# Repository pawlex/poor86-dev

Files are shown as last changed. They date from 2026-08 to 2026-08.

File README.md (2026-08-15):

# Poor86

A 386/486-class PC motherboard, in mini-ITX, built around a real x86 CPU
and an FPGA chipset — with every part of the machine that nobody loves
replaced by something modern.

It boots DOS. It has no hard disk, no battery, no legacy expansion
slots, no drive bays, and no shelf of discs. It fits in a case you can live with.

Decisions here are made on latency and phase coupling rather than raw
bandwidth: at 33 MHz with a four-word burst window, bandwidth is rarely
what binds. Slack is left in deliberately — spare capacity is usually
where the next idea lands.

Constraints are stated before solutions, and the reasoning behind each
decision is written down, wrong turns included. Source records what was
built; only a decision record explains why. That record is where the
project actually lives, and it is what would let someone else continue
the work rather than restart it.

---

## Why

### Love of the game

The interesting engineering is still here. A 486 local bus with burst
transfers, write-back cache control and coherency is a genuinely hard
problem, and building a chipset front end for it in programmable logic
is the kind of work that is worth doing for its own sake. The memory
subsystem and the bus interface caching are the heart of this project —
and they are deliberately scheduled **last**, because starting with the
best part is how the other ninety percent never gets finished.

### Giving back

The retro community has already solved most of the practical problems of
keeping these machines alive — floppy emulators, IDE replacements,
sound cards on modern microcontrollers, video scalers, USB adapters.
They exist as separate projects, separate purchases and separate wiring.

This assembles them into one board, and gives the work back: open
hardware, open RTL, and an entirely open toolchain (yosys, nextpnr,
Verilator — no vendor tools anywhere in the flow). Fixes found in
upstream projects go back upstream.

### The effort is already worth it, finished or not

This sat as an idea for years. Not for lack of interest — for lack of
time against its scope. It spans PCB design, an FPGA chipset, period bus
protocols, firmware, x86 emulation and controller software, and each of
those is somebody's full-time specialism. Any one of them is a weekend.
All of them together is a wall.

These sub-projects had been put off for years because they are hard —
but they are hard in a specific way that is worth naming, because it
changes what to do about them. **Most of them are wide, not deep.**

A deep problem needs insight you do not yet have. A wide one needs you
to be fluent in a domain you are not fluent in: the SeaBIOS source tree,
a Cirrus register map, an ECP5 memory primitive, the ATAPI packet
interface. Every step is tractable; the cost is the ramp-up, and it
resets every time you put the project down. That is precisely why wide
problems stall on evenings and weekends — the evening goes on reloading
context and never reaches the work.

Very little of the progress here came from cleverness. A months-old
question about the bus was answered by running one existing emulator
configuration. The peripheral models turned out to already exist in a
fork of the project. The video BIOS itself specified what the hardware
must implement, once somebody read it. None of that was hard. It was
*unread*.

Which leaves the genuinely deep part — the memory subsystem and the bus
interface caching — as the smallest fraction of the work, and the part
the author is actually equipped for. The wall was never the interesting
problem. It was the dozen uninteresting ones standing in front of it.

Working with an AI assistant (Claude) is what got past them. **And the
point worth making plainly is this: even if the board is never finished,
the effort has not been wasted.** Real problems have been solved, and they
stand on their own:

- **A working co-simulation harness.** An x86 interpreter running
  natively drives real RTL through a Wishbone bus-functional model, so
  chipset logic can be developed and regression-tested without a CPU in
  the simulation. It is reusable well beyond this project.
- **SeaBIOS completes POST against it**, on a non-PCI ISA machine with a
  deliberately minimal device set — a reproducible configuration, not a
  one-off.
- **A real bug found upstream**, in the tiny386 interpreter: its
  instruction-fetch cache retained a physical address for MMIO pages,
  reading out of bounds. Fixed, documented, and a candidate to send
  back.
- **A bounded specification for Cirrus-compatible video**, derived by
  reading what the video BIOS actually touches rather than guessing —
  including the finding that the blitter is not required at all.
- **Measured budgets rather than assumed ones** — bitstream size, block
  RAM limits, LUT and timing figures across candidate cores.

The larger shift is harder to point at but matters more. **A great deal
of this design has moved from "it could be done, with caveats" into an
active plan** — decisions made, alternatives eliminated for stated
reasons, and the reasoning written down where it can be checked. The
caveats that remain are now specific and small enough to attack.

Every decision here is the author's. The assistance is in reach and
throughput, and in not losing the reasoning between sessions — which,
for a project this wide worked on in evenings, turns out to be the
binding constraint.

**So this is also a case study**, kept in the open so it can be judged
rather than claimed. What has characterised it: check for the existing
thing before building a new one; measure instead of arguing; and keep
the corrections on the record — several conclusions in
[docs/PLAN_OF_RECORD.md](docs/PLAN_OF_RECORD.md) reversed once evidence arrived,
and the superseded reasoning still sits beside what replaced it.

There is a lot of noise about what this technology is for. This is one
answer: **real engineering problems, not cat videos.**

### Not just nostalgia

Nostalgia would mean reproducing a 1993 machine faithfully, defects
included, and accepting that it is expensive, fragile and annoying to
own. That is a museum piece.

The aim is different: **the era should be accessible to people who were
priced out of it, and pleasant enough to actually use.** Period hardware
has become scarce and costly; a working machine is now several hundred
pounds of separate purchases plus ongoing maintenance. This should cost
a fraction of that and ask nothing of its owner beyond plugging it in.

That said — the specific machines are not arbitrary. **A 386SX was the
author's first computer, and a 486SLC2 the first upgrade, paid for with
paper-round money.** Those configurations are a requirement, not a
technical trade-off. Everything modern in this design exists so that
*those* machines can be delivered without the burden that otherwise
makes them unusable.

---

## The organising principle

> **Authenticity is required at the guest-visible register interface.
> Everything behind it should be modern.**

A real x86 is soldered to this board. It, and the DOS software above it,
can only see registers and bus cycles — so that is the only place
period-correctness buys anything. Behind that boundary, reproducing 1993
is cost without benefit, and frequently worse: analogue output stages,
battery-backed NVRAM and spinning media are things to be rid of, not
honoured.

| | authentic front end | modern back end |
|---|---|---|
| storage | IDE / ATAPI registers | controller-served images |
| network | NE2000 registers | WiFi |
| keyboard, mouse | 8042 and PS/2 | USB HID |
| video | Cirrus-compatible registers | HDMI, or real CL-GD5428 for a CRT |
| RTC and CMOS | 128 legacy registers | NTP, no battery |
| sound | SB16 / AdLib registers | software synthesis, modern DAC |

Two corollaries that have saved a great deal of work:

- **Do not own what you can inherit.** SeaBIOS and SeaVGABIOS already
  support this machine. Shape the hardware so their existing code paths
  apply, rather than writing or patching firmware.
- **Do not reinvent what already exists.** Check first. Most of what
  this project needs has been found rather than written.

---

## Goals

- **Boots DOS**, on real x86 silicon, out of the box, with nothing
  attached.
- **mini-ITX (170 x 170 mm)**, in a case that can live on a desk.
- **Low bill of materials.** Every function moved into the FPGA or the
  board controller is a part that does not have to be bought, fitted or
  sourced.
- **Open end to end** — hardware, RTL, and toolchain.
- **No maintenance burden.** No battery to replace, no drive to fail, no
  media to store.
- **Usable by someone who is not the author**, which is a higher bar
  than working.

### Non-goals

- Museum-grade period accuracy behind the register interface.
- **Legacy expansion slots.** They do not fit the form factor, and
  building around scarce period cards is a dead end. Specific legacy
  silicon is supported directly, on a mezzanine; new work arrives on a
  modern header.
- Windows. DOS is the target; anything further is a bonus.
- Being the fastest anything. A period machine that works beats a fast
  one that does not exist.

---

## What is on the board

- **A soldered x86.** A 386/486 SL/SLC-class part, or an **Am5x86-133**
  — abundant as NOS, 486DX4-class, and the part that makes the machine
  more than a curiosity. **3.3 V is a requirement**, because it lets the
  entire CPU bus connect to the FPGA without level shifters — plausibly
  the largest single saving in the design.
- **An ECP5 FPGA** carrying the chipset and the peripherals, so a
  discrete 8259, 8254, 8042 and NE2000 are LUTs rather than packages.
- **An ESP32** as board controller: NTP for the clock, WiFi for the
  network, and the back end for storage.
- **A RISC-V soft core** inside the FPGA, which serves fallback
  configuration when the controller is unavailable, and which can run an
  x86 interpreter so that a board works with no period CPU fitted at all.
- **Video**, either from the FPGA over HDMI, or a real **CL-GD5428** on
  the local bus for driving a CRT.

General placement of the Poor86 board

*General placement only — orientation is not fixed. What is fixed is
which block connects to which FPGA edge, because that is derivable from
the datasheets now rather than discovered during layout. Pin counts are
counted from `Data/pinmap_*.csv`, not estimated. See
[PLACEMENT.md](docs/PLACEMENT.md).*

---

## Sub-projects

| repo | what it is | why it exists |
|---|---|---|
| [vexrv-cpu-oss](https://github.com/pawlex/vexrv-cpu-oss) | the RISC-V soft core, the x86 interpreter payload, and the Verilator co-simulation | the chipset is developed and debugged against it, so most of the machine can be made to work before a board exists |
| [ao486-cpu-oss](https://github.com/pawlex/ao486-cpu-oss) | the ao486 486-class x86 soft core packaged for the open toolchain — Verilator regression suite, plus synthesis and place-and-route with no vendor tools. Places and routes on an ECP5-85F at 32.87 MHz | **so the machine outlives the supply of period CPUs.** NOS Am5x86 is finite and not being made again; when it runs out, the board has to remain buildable, and a 486-class core inside the FPGA is how |
| [tiny386](https://github.com/pawlex/tiny386) | fork of the x86 interpreter, ported to bare-metal RV32 | gives the soft core an x86 to run, so a board with no period CPU fitted at all still boots |
| [ecp5-oss-skeleton](https://github.com/pawlex/ecp5-oss-skeleton) | ECP5 project template and the block-RAM findings behind it | keeps the entire flow on open tooling, with no vendor toolchain anywhere in it |

Firmware comes from [SeaBIOS](https://www.seabios.org/) and SeaVGABIOS,
unmodified where possible.

---

## Status

Early. The schematics and library work are in `PCB/`; reference material
is in `Data/`.

On the simulation side, SeaBIOS already completes POST against the
chipset model in Verilator, with real RTL in the transaction path.

**The memory subsystem and the bus interface caching are deliberately
unspecified.** They are the most interesting part of the work and they
are being left until the rest is done.

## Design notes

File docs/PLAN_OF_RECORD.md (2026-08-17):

# Plan of record

The architecture record for Poor86: what is decided, what is open, and
**why** — including the reasoning that was wrong on the way, because a
decision without its rejected alternatives tends to get re-litigated.

Motivation, goals and the organising principle are in
[../README.md](../README.md). This file is the detail beneath them.

Two conventions carried throughout:

- **If a decision would assume a particular memory-subsystem design, it
  is flagged rather than assumed.** The memory subsystem is being
  specified last, deliberately.
- **Corrections stay on the record.** Several conclusions here reversed
  once evidence arrived; the superseded reasoning is kept beside what
  replaced it.

Implementation and the simulation environment live in
[vexrv-cpu-oss](https://github.com/pawlex/vexrv-cpu-oss).

## Status: nothing here is built, and almost nothing is chosen

**Read this first.** *Plan of record* is meant literally: this is the
currently-agreed plan, and it is expected to change. It is not a
specification and it is not a commitment.

No hardware exists. Nothing is committed to, nothing is irreversible,
and several conclusions in this document reversed within the
conversation that produced them. What exists is a co-simulation, some
measurements, and a set of things that have been **ruled out**.

That is not a weak position. **Ruling something out is forward
progress, and the more durable kind** — an elimination backed by a
reason survives new information, where a selection made early usually
does not. "PCI is out, because the bus is 16-bit and SeaBIOS supports
non-PCI as a first-class configuration" stays true regardless of what
comes next. "We will use serial PSRAM" would not.

So the headings are labelled by what they actually are:

| label | meaning |
|---|---|
| **Requirement** | given as a constraint, not derived here. Not up for re-derivation. |
| **Eliminated** | ruled out, with a reason intended to outlive the moment |
| **Direction** | the current preference and its reasoning. **Not settled.** |
| **Design goal** | a property the machine should have |
| **OPEN** | actively unresolved, and blocking something |

A record is allowed to hold two positions in tension; a specification is
not. **This is a record.** Where two sections disagree — and some do,
marked *Contested* — that is the document working correctly, not a
defect to be tidied away.

## Requirement: one soldered CPU, SX-class bus, 3.3 V

**There is no socket.** All parts are soldered down, and there is exactly
one CPU — a **386/486 SL/SLC-class part in PGA100, 3.3 V VCC**.

That resolves what looked like the hard decision. The cost weighted
heaviest — two bus front ends for a dual-socket board — **does not
exist**. There is one bus, one front end, one set of validation.

### What follows

```
  one SX-class CPU  ->  16-bit data, 24-bit address
                    ->  no PCI (32-bit, anachronistic)
                    ->  no VL-Bus slot; local-bus video still fine
                    ->  ISA-class programming model
                    ->  16 MiB guest RAM ceiling
```

The ceiling is now a property of the machine rather than of which part
someone fitted, which is simpler to design and document against.

### 3.3 V is the important part

**A 3.3 V CPU interfaces directly to the ECP5.** The FPGA's I/O banks
drive and receive LVCMOS33, so the entire CPU bus — every address, data
and control line — connects without level shifters.

At 5 V this would need translation on dozens of signals: parts, board
area, propagation delay on the timing-critical path, and a failure mode
on every one of them. Requiring 3.3 V removes all of it. This is
plausibly the single largest BOM and area saving in the design, and it
is consistent with the mini-ITX and cost goals.

### Why SL/SLC is a good fit beyond the voltage

The SLC-class parts pair a **386SX-style bus with the 486 instruction
set** and a small on-chip cache. So the chipset sees the simpler 16/24
bus while the software sees a 486 — better compatibility for the same
front-end effort. They are also low power, need no heatsink, and come in
a package that suits mini-ITX far better than a 486 PGA with a cooler
on top.

### The 486 part: Am5x86-133

For the record, the 486-class option is an **Am5x86 at 133 MHz**,
abundantly available as NOS — which answers the sourcing concern raised
against period parts elsewhere. It is 486DX4-class with a 16 KiB
write-back L1, and **3.3 V**, so the no-level-shifter property above
holds for it as well.

**Its bus is 33 MHz, not 133.** The 133 is a 4x internal multiplier. The
FPGA chipset only ever has to meet the 33 MHz bus, and against the Fmax
figures already measured on this device — VexRiscv variants at 99-108
MHz, ao486 at 32.87 MHz out-of-context — that is roughly 3x headroom on
the front end. It stays comfortable as the device fills.

### ...and it brings the hardest chipset problem

The Am5x86 is the fast part *and* the difficult one. Its bus is **32-bit,
bursting, pipelined, with cache control** — and with a **write-back L1**,
which is the part that hurts.

What the chipset has to deal with that an SX-class bus does not:

| signal / behaviour | why it is work |
|---|---|
| `BRDY#` / `BLAST#` bursts | 4-transfer cache line fills, not single cycles |
| `KEN#` | the chipset decides, per cycle, what is cacheable |
| `FLUSH#` | forced write-back and invalidate |
| `AHOLD` / `EADS#` / `INV` | snooping — an external address driven *into* the CPU |
| write-back L1 | **the CPU can hold dirty lines the chipset does not have** |

That last row is the real problem, and it is a *coherency* problem rather
than a timing one. Anything else writing guest memory — the ESP32
serving storage, the soft core, any DMA-equivalent — can be writing
underneath a dirty line the CPU has not flushed.

Three ways out, in increasing order of cost:

**A.** **Never assert `KEN#`.** External memory is uncacheable, the L1 is
   effectively disabled, coherency evaporates. Simplest possible chipset
   — and throws away most of what the 133 MHz part was bought for.
**B.** **Cacheable but no burst.** Assert `KEN#`, answer each of the four
   transfers with a normal ready rather than `BRDY#`. Line fills cost 4
   cycles instead of a burst, but the cache works. Still needs a
   coherency answer.

**C.** **Selective cacheability plus snooping.** `KEN#` asserted only for
   regions no other agent writes, snooping via `AHOLD`/`EADS#` for the
   rest. Fastest and hardest. A behavioural sketch of this one exists —
   see [BIU_MEMSS.md](BIU_MEMSS.md), **Concept C** — which is an
   exploration, not a proposal.

Note (A) and (B) make the *coherency* question mostly disappear, which is
worth weighing: the difficulty is not evenly distributed across the
options.

**Deliberately deferred.** Burst and caching support are not on the
critical path to a first board. The soft core makes the hardware useful
without them, so this is scheduled after production rather than before
it — and it is another reason the memory subsystem stays open, since the
cacheability and coherency policy is downstream of what sits behind the
BIU.

- [ ] **Masked writes, or full cache-line writes with read-fill?**
      Does the memory controller honour byte enables via `DQM`, or does it
      only ever write whole lines — turning any partial write into a
      **read-modify-write**?

      **The cost of getting it wrong is latency, on the path the whole
      design is organised around.** An RMW pays a full read before the
      write: `tRCD` + `CL` ≈ 60 ns at 66 MHz, against a 30 ns CPU cycle.
      **`DQM` masking costs nothing** — the two pins are already in the
      budget and SDRAM supports it natively.

      **The 32→16 split maps byte enables cleanly.** A 32-bit CPU write is
      two 16-bit SDRAM cycles, so `BE0`/`BE1` become the first cycle's
      `DQM[1:0]` and `BE2`/`BE3` the second. No encoding problem.

      **But it is coupled to the cache policy below, and may be moot.**
      With **write-back plus write-allocate**, partial writes land in the
      cache and lines are written back whole — `DQM` is then barely
      exercised. With **write-through, no-allocate, or any uncached
      region**, partial writes reach memory directly and masking becomes
      essential. **Decide the cache policy first; this follows from it.**

      **The video path does not share the question.** QSPI PSRAM is
      byte-addressable — a write command carries a byte address — so the
      write-combining buffer flushes only its dirty bytes with no masking
      and no RMW. **This is an SDRAM-side question only.**

      **Worth exploring — a write-allocate queue.** Rather than draining a
      partial write immediately, hold it briefly and see whether adjacent
      writes follow. Sequential patterns — `REP STOSD`, `memcpy`, structure
      initialisation — then coalesce into **full lines, which need neither
      masking nor RMW.**

      **Not write-back caching.** No tag array, no coherency claim, no
      snoop obligation outward; a bounded queue that drains eagerly on
      idle, on fill, or on a read that touches it. It sits *below* the
      cache and therefore does not complicate the cache policy — which is
      what makes it explorable independently of the decision above.

      > **The same structure as the video write-combining buffer**, one
      > level over: lines, dirty masks, flush when full. **Two instances of
      > one design rather than two designs** — worth building it
      > parameterised.

      **One difference from the video instance — and it is not read
      volume.** The video memory controller is **read-dominated**: scanout
      streams ~47 MB/s at 1024×768 and is by far its heaviest traffic.
      What is rare there is *host* reads coming back up.

      **The distinction that matters is which reads must be coherent with
      pending writes:**

      | | dominant reader | needs coherency with the buffer? |
      |---|---|---|
      | **video MC** | **scanout** | **no** — a pixel one frame late is invisible |
      | | host read-modify-write | yes, but rare → *flush-on-read* is cheap |
      | **main memory MC** | **CPU** | **yes, always** → must snoop |

      > **So "flush on read" on the video side means *host* reads only.**
      > Applying it to scanout would flush the buffer on every burst and
      > **destroy the write combining it exists for.** The dominant reader
      > deliberately bypasses the buffer entirely.

      On the main-memory side the dominant reader is also the one needing
      coherency, so **snooping is mandatory** — at four to eight entries a
      comparator array, not a CAM in the expensive sense.

      **It reduces how often masking is needed; it does not remove the
      need.** Genuinely scattered byte writes still reach memory alone.

      > **HARDWARE DECIDED: `DQM[1:0]` are *present* — routed to the
      > connector and to the FPGA.** Two pins, already counted inside the
      > group of 40.
      >
      > **Present, not enabled.** Whether the controller drives them
      > meaningfully is an RTL question and stays open below. **This does
      > not wait on the protocol** — the pins are the irreversible layer,
      > the protocol is not, so the board carries the capability and the
      > RTL decides whether to exercise it. Same ordering the mezzanine
      > specification follows.

- [ ] **OPEN — where does the write-allocate queue sit in the coherency
      protocol?** This is the part still to reconcile, and it is separate
      from the cache policy question below.

      **The queue is a third place data can live** — after the 486's
      internal write-back L1 and the FPGA's L2 — and anything that reads
      memory must account for it.

      | reader | obligation |
      |---|---|
      | CPU reads | snoop the queue — comparator array, 4–8 entries |
      | the L2 | ordering against a line that is both cached and queued |
      | external masters / DMA | must not read stale memory behind a pending write |
      | video scanout | **none** — separate PSRAM, never CPU traffic |

      **Three shapes to choose between:**

      1. **Flush before any external access.** Simplest and obviously
         correct; costs latency on every DMA touch.
      2. **Snoop the queue alongside the L2.** No flush penalty, more
         logic, and the queue joins the `AHOLD`/`EADS`/`HITM`/`INV`
         machinery rather than hiding beneath it.
      3. **Keep it non-coherent and CPU-region-only.** Cheapest, but
         limits where it may be used and needs the boundary defined.

      **Decide this before the queue is built, not after** — it determines
      whether the queue is a private optimisation beneath the coherency
      domain or a participant inside it, and that is structural rather than
      tunable.

- [ ] Decide the cacheability and coherency policy when the Am5x86 front
      end is built. Note the existing BIU decision — protocol-correct,
      structured so wait states and bursts can be added later — was taken
      against a simpler bus, and on a write-back 486 bursts and `KEN#`
      change what the front end *is* rather than extending it.

### The risk this sequencing creates, and the cheap insurance

Shipping the board before the hard-CPU front end exists means **the PCB
commits to a bus interface that has never been exercised.** Layout,
termination and pin assignment are frozen at production while the logic
that drives them is still hypothetical. That is a respin risk, and the
mitigations are cheap only if taken up front:

- [ ] **Route every CPU signal to the FPGA**, including ones the first
      chipset ignores — `KEN#`, `FLUSH#`, `AHOLD`, `EADS#`, `BRDY#`,
      `BLAST#`, `INV`, byte enables, everything. A programmable chipset
      can start using a signal later; it cannot use one that was never
      connected. Omitting "unneeded" pins is the single most likely
      cause of a respin here.
- [ ] **Leave spare FPGA I/O and keep banks flexible.** The same
      argument.
- [ ] **Be conservative on the bus at 33 MHz** — trace lengths,
      termination, and clock distribution — since the timing-critical
      path cannot be validated on hardware until the front end exists.
- [ ] Consider whether a first board can be brought up with **no x86
      fitted at all**, which removes NOS sourcing from the bring-up
      critical path entirely.
- [ ] Note the asymmetry this creates between SKUs: the SX-class part
      needs none of this. **The cheap CPU has the cheap chipset and the
      fast CPU has the expensive one**, so the two variants are not
      equally far from done.

### One BIU per CPU variant, sharing everything below it

**The BIU is per-variant, not universal.** The SX-class BIU omits `KEN#`
and burst because its CPU has neither; the Am5x86 BIU carries them from
the start, because retrofitting burst restructures a front end rather
than extending it.

This follows from decisions already made rather than adding a new idea:

- **The cache is already the abstraction boundary.** If DRAM width is
  invisible *above* it, CPU bus protocol should be invisible *below* it.
  Swappable BIUs is that same principle applied upward.
- **Only one is instantiated per bitstream**, so two source modules cost
  no area — the "bitstream difference, not a redesign" argument again.
- **It matches the sequencing.** The SX BIU can be finished, verified and
  shipping while the Am5x86 one is still being developed. A single
  unified BIU could not be: the easy path would be blocked on the hard
  one.
- Each module is smaller, with a smaller state space, and is therefore
  easier to verify than one conditional-laden module spanning both.

#### The requirement this creates

**Every BIU must present an identical interface to L2.** If the two hand
the cache different contracts, the variation has not been eliminated —
it has been pushed downstream into the cache, which then has to handle
both. That buys two front ends *and* a more complicated back end, which
is worse than either alternative.

So the L2-facing interface is fixed **first**, and the BIUs conform to
it. It must not emerge from whichever BIU happens to get written first.

#### The divergence risk, which needs active care

**Address decode, region cacheability and the posted-write buffer are
common to both BIUs.** Copy-pasted into two modules they *will* diverge
silently — one receives a fix the other does not, and the difference
surfaces as a bug in whichever variant was not being tested that week.

They want factoring into shared blocks, leaving each BIU as genuinely
only the bus-protocol layer. **This is the specific thing that makes or
breaks the multi-BIU model**, and it is a discipline rather than a
design: nothing prevents the duplication except deciding not to.

#### SX-class parts may have L1 — design for its presence

**Settled: assume an SX-class CPU may carry an L1.** The reference for
the capable end is the **TI 486SXLC2** — 386SX-pin-compatible, but with
an on-die cache and clock doubling. So "SX-class" describes the *bus*,
not the absence of a cache, and the SX BIU cannot assume there is
nothing above it.

That reopens the L1 write policy question on the cheap variant. SX-class
caches differ by vendor in whether they are write-through or write-back,
and the difference is not cosmetic: **write-through makes the coherency
problem largely vanish on that variant; write-back reproduces the
Am5x86's problem on the cheap CPU.** Unverified for the specific parts.

##### Settled: only cached SX-class parts are designed for

**Assume L1 is present.** The SX BIU is built for a CPU that has a
cache, and no BIU variant is written for an uncached part.

The 3.3 V requirement had largely decided this already. Uncached
SX-class parts are overwhelmingly **5 V**, which puts them outside the
supported set on voltage grounds before cache is considered at all — the
Intel 386SX-16 among them. The lone 3.3 V uncached candidate is the
**AMD 386SXL**, and holding a design decision open for a single part of
uncertain availability is not a trade worth making.

Nor would anyone reasonably choose an uncached 386SX-16 on this
platform, given what else it can be built with.

**What this buys:** `KEN#` and `FLUSH#` are always present, the SX BIU
has one shape rather than two, and the multi-BIU set stays at two
members rather than three.

**What it does not do is foreclose anything.** The CPU is soldered, so a
board is built for one part regardless; an uncached part would simply
leave the cache control signals unused, which the BIU can be
reconfigured for if it ever matters. This is "not designed for", not
"cannot work".

##### One tension worth naming, not reopening

The requirement provenance records **two** machines as the reason the
project exists: a 386SX as a first computer, and a 486SLC2 as the first
upgrade. This decision keeps the SLC2 class and excludes the plain 386SX
— on voltage and availability, which are real constraints rather than
preferences.

Recorded so it is a conscious trade rather than a silent drift. If the
386SX specifically matters more than the reasoning above, this is the
decision to revisit, and the cost of revisiting it is one more BIU
variant.

- [ ] **Compare the datasheets across the cached SX-class parts** — TI
      486SXLC2, Cyrix 486SLC, IBM 486SLC2 — and establish whether their
      pinouts actually agree. The original framing of this task was
      "most advanced versus least advanced"; with the uncached parts out
      of scope, the real question is whether the *cached* parts are
      mutually compatible.

      The trap remains renaming rather than addition: cache and
      power-management control on these parts lands on pins the base
      386SX pinout used differently or left unconnected. A pin that is
      NC on one part and `FLUSH#` on another is invisible in a pin-count
      comparison and fatal in layout.

      **This is precisely the case the "route every CPU signal to the
      FPGA" rule exists for.** The BIU can be told which part is fitted
      at bitstream time; the PCB cannot be told anything after
      fabrication.

#### What this resolves

- **The burst contradiction dissolves.** "Structured so bursts can be
  added later" and "bursts change what the front end is" are both true,
  scoped to different BIUs. Neither statement was wrong; the assumption
  of a single BIU spanning both variants was.
- **The SX cost becomes precise.** Not "2x or 1.2x" — **the BIU doubles,
  the memory subsystem does not.** Two front ends, one cache, one LLC,
  one memory controller.

### Two CPU options: a bitstream difference, and a footprint problem

If both an SLC-class part and the Am5x86 are offered, they differ in bus
width (16/24 versus 32) and therefore in chipset front end. Two useful
observations:

- **In an FPGA that is a bitstream difference, not a redesign.** The
  front end can be built per variant and selected at configuration time.
  This is a real advantage of putting the chipset in programmable logic
  and is worth exploiting rather than avoiding.
- **The PCB is the harder half.** The packages differ, so this is either
  two board variants or one board carrying both footprints with only one
  populated. That is an area question on a 170 mm square board, not a
  logic question.

### The soft core's role varies by SKU — and that has a consequence

An Am5x86-133 buyer is unlikely to care whether the tiny386 soft core
runs at all. Which implies the soft core matters most at the *other* end
of the range — plausibly a SKU with **no x86 part fitted at all**,
where the VexRiscv running tiny386 *is* the CPU. That is the cheapest
possible BOM and has no period-parts sourcing constraint, which fits the
cost positioning well.

**If that is a shipping configuration, two things recorded elsewhere stop
being true and need revisiting.** Both currently justify themselves on
tiny386 being a validation vehicle only:

1. **"Performance is explicitly not a design input."** True for a
   validation vehicle. False for a SKU somebody buys.
2. **"The guest region is uncached in the MCU."** That was decided so
   guest traffic *reaches the BIU and is observable in Verilator* —
   deliberately trading speed for visibility. As a product configuration
   it means every guest memory access pays a bus round trip, which is
   the dominant cost in an interpreter.

Rough order of magnitude, to make the discussion concrete rather than
abstract: VexRiscv at ~100 MHz against tiny386's ~100 host instructions
per emulated instruction is on the order of **1 M x86 instructions/sec**
— period-plausible for an early 386SX, and genuinely usable for DOS.
**But that estimate assumes cached guest memory.** With every access
crossing the BIU uncached it would be substantially worse, and the gap
is the size of the conflict above.

**Resolved by sequencing: it is both, in order.** The soft core is the
path that gets the hardware design locked in and into production *before*
the hard-CPU chipset is finished. First boards are useful with no x86
part fitted at all; the Am5x86 front end lands later as a bitstream.

That is only possible because the chipset is in programmable logic, and
it is worth stating as a deliberate strategy rather than a happy
accident: **the board can ship before the chipset is complete.**

So the caching question is real but **not now**. Getting something into
the community's hands beats optimising a path nobody has yet used.

- [ ] Revisit "the guest region is uncached in the MCU" when soft-core
      performance actually matters — not before.

- [ ] **Keep one machine definition across variants.** A 486 variant
      *could* support VL-Bus or PCI, but diverging would mean two
      peripheral sets, two BIOS configurations and two software stories.
      The ISA-class definition is very likely still right for both — but
      it should be a decision, not drift.

### Consequences worth recording

- **No CPU choice for the user, and no upgrade path.** The machine is an
  appliance, which fits "a nice package for the enthusiast" but should be
  a deliberate position rather than a side effect.
- **Sourcing.** 3.3 V parts of this era are a narrower field than 5 V
  ones, and this is a build-volume constraint like the GD5428.
- **Terminology.** Documents here say "the hard CPU in the socket". It
  is soldered; the reasoning is unchanged — a real x86 is present and
  therefore the guest-visible interfaces must be period-correct — but
  the phrasing should be corrected as files are touched.
- The GD5428 attach question is simplified too: there is only one bus for
  it to match.

## Eliminated: PCI (follows from the above)

**PCI is out.** It pushes real complexity onto the chipset — configuration
space, BAR allocation, interrupt routing — for a device set that is
fixed, known, and entirely ISA-class at the register level (IDE at
`0x1f0`/`0x170`, NE2000 at `0x300`, SB16 at `0x220`, VGA at `0x3c0`,
8042, 8259, 8254, RTC).

This chooses the **programming model the guest sees**, not connectors.
With peripherals as FPGA logic there are no physical slots either way.

### The evidence

SeaBIOS supports non-PCI as a first-class configuration. QEMU's `isapc`
machine loads the **identical `bios.bin`** — one binary, decided at
runtime:

```
addr=00000000fffe0000 size=0x020000 mem=ram name="bios.bin"
...
Detected non-PCI system
ATA controller 1 at 1f0/3f4/0 (irq 14 dev ffffffff)
ATA controller 2 at 170/374/0 (irq 15 dev ffffffff)
Running option rom at c000:0003            <- ISA VGA
DVD/CD [ata1-0: QEMU DVD-ROM ATAPI-4 DVD/CD]
```

Legacy IDE works, drives attach and are bootable, and video comes up
through an ISA option ROM. Our machine with the i440FX/PIIX3 removed
produces the same `Detected non-PCI system` and the same ATA controllers
at `dev ffffffff`, and completes POST.

### Correction: this supersedes the `bios-geometry` plan

An earlier entry recorded drive geometry arriving as a `bios-geometry`
fw_cfg file. **That does not work on a non-PCI machine:**

```c
int boot_lchs_find_ata_device(struct pci_device *pci, ...)
{
    if (!CONFIG_HOST_BIOS_GEOMETRY) return -1;
    if (!pci) return -1;      // support only pci machine for now
```

So geometry falls back to the legacy CMOS type-47 bytes, populated by
the reset-exit vector, plus SeaBIOS's own translation from IDENTIFY.
The CMOS bytes had to be populated anyway for guests that bypass the
BIOS, so this costs a channel rather than a capability.

- [ ] Drop `bios-geometry` from the reset-image plan; keep `bootorder`,
      which does not depend on PCI.

## Direction: HDMI on-board, framebuffer in external DRAM

**On-board video is HDMI driven directly from the ECP5** ("fake TMDS" —
differential pairs from the FPGA's own I/O, no transmitter chip). The
**framebuffer lives in external DRAM.**

That is a decision with a dependency attached, and it is the reason the
memory subsystem stays deferred: **the video path crosses it.** Flagged
rather than assumed, per the standing convention.

On-chip is not an option, and the arithmetic is worth keeping so it is
not re-litigated. An LFE5U-85F has 208 EBR x 18,432 bits = 468 KiB
total:

| | bits | EBR at ideal packing |
|---|---|---|
| VGA 256 KiB (4 planes x 64 KiB, no byte enables) | 2.1 Mbit | ~114 of 208 — ~55%, tight but possible |
| SVGA 1 MiB | 8.4 Mbit | impossible |

(An earlier note here applied the ~44% efficiency measured for
*byte-enabled* BRAM to VGA planes, which do not need byte enables. That
was wrong and is corrected above. The conclusion is unchanged for SVGA
and only becomes arguable for plain VGA.)

Driving a CRT does **not** by itself require a real card: an FPGA drives
analog RGB through a DAC with PLL-generated 25.175/28.322 MHz pixel
clocks. Authenticity of *output* and depth of *register compatibility*
are separable questions.

- [ ] **VLB is still on the table** for optional real VGA hardware, as a
      separate path from on-board HDMI. Specification pending; not
      recorded here.

### OPEN: can HDMI be driven the cheap way, and does video share memory?

Two questions, in order, because the first gates the second — and the
second gates the memory part, which gates the cache.

#### 1. Can "fake TMDS" from the ECP5 actually drive a display?

Driving the DVI/HDMI differential pairs directly from FPGA outputs, with
no transmitter chip. If this does not work the FPGA video path does not
exist, a real CL-GD5428 becomes the only display option, and scanout
leaves the memory subsystem entirely.

**Starting points, links and the arithmetic are in
[FAKE_TMDS.md](FAKE_TMDS.md).** Short version: the ULX3S is an ECP5-85F
board that already does this over a TMDS-tolerant LVDS connector using
the ECP5's own `ODDRX1F`, with two open implementations to work from —
so **no custom hardware is needed to answer the question.**

- [ ] Run the feasibility study. Not started, and not urgent *provided*
      the decoupling below is taken.

#### 2. If FPGA video exists, does its framebuffer share CPU memory?

This is the coupling that makes the question urgent rather than
cosmetic:

| video path | framebuffer | scanout on the memory subsystem |
|---|---|---|
| CL-GD5428 | the chip's own DRAM | **none** |
| FPGA to HDMI | external DRAM | **~135 MB/s** at 1024x768x24 |

**If both paths are options on the same PCB, the shared case wins by
default** — the board must support FPGA video whether or not a GD5428 is
fitted, so the memory has to carry scanout regardless.

The chain worth keeping in view: **which video output -> which memory
part -> what the cache must do.** An apparently peripheral display
decision sits upstream of the memory subsystem and the cache.

#### Governing principle: do not design the memory subsystem around video

**The video unit is a question mark, and the memory subsystem must not
be designed around a question mark.** Everything downstream of the
memory choice — the cache, the LLC, the thing this project is actually
for — would then be resting on an unresolved display decision.

Two ways out, and they are not exclusive:

- **Collapse the question mark early.** Prove or disprove fake-TMDS
  output on existing hardware, before it can constrain anything. Cheap,
  and see the prior art below.
- **Decouple permanently: give video its own memory channel.** Serial
  parts make an extra channel nearly free in pins, and unpopulated
  footprints cost nothing in BOM. The two clients then separate
  entirely — CPU memory chosen for latency, video memory for bandwidth,
  both video paths supportable, no arbitration, and **no dependency of
  the memory subsystem on the video decision at all.**

The second is the stronger answer, because it holds even if the video
decision changes later. It reduces a coupled architectural question to a
pin-assignment decision.

#### Proposed resolution: video never touches the SDRAM

**The objection to sharing is not bandwidth.** SDRAM has ample bandwidth for CPU and video together. **The objection is what
sharing does to the memory controller** — and to the ordering this
document already commits to.

- **It breaks the stated design order.** *"Establish the latency budget
  from the CPU side first; it is the fixed constraint."* **A latency
  budget cannot be fixed if a scanout engine may interrupt it.** Sharing
  turns the fixed constraint into a variable one.
- **The two access patterns are pathological for each other.** Scanout is
  long and sequential; CPU access is short and random. In a page-based
  memory **each closes the other's open row**, so the cost appears as
  latency variance rather than as a bandwidth shortfall that could be
  budgeted.
- **It makes the arbiter a real-time problem.** Video has hard deadlines
  and the CPU does not, so video must win — which means CPU latency is
  set by video activity, and contention bugs only appear under load.

**Both private-memory options are already on the board:**

| | capacity | scanout ceiling | cost |
|---|---|---|---|
| **BRAM** | 468 KB total | 640×480×8 = **300 KB, 64% of it** | competes directly with the L2 cache |
| **QSPI PSRAM** | 8 MB | ~38 MB/s → **640×480×8 at ~66% used** | half-duplex; CPU writes need combining |

##### Decided: two QSPI PSRAMs, ganged ×8

**One ×4 device is a little shy; two are comfortable.** They share `CLK`
and chip select — being ganged, they behave as one device — with separate
data nibbles. The FPGA drives both nibbles identically during command and
address, then reads **8 bits per clock** and assembles bytes from the two
halves. The NOR stays on the same bus using `D[3:0]` and its own select.

| | pins |
|---|---:|
| **common `CLK`**, shared by all three devices | 1 |
| PSRAM A — `D[3:0]` + `CS_A` | 5 |
| PSRAM B — `D[7:4]` + `CS_B` | 5 |
| NOR — own `D[3:0]` + `CS_N` | 5 |
| **total** | **16** |

**The NOR gets its own data lines.** Video scanout is continuous and
real-time, so sharing wires with the flash means a NOR read can stall a
scanout burst — **a visible artifact, not a latency statistic.** The
common clock is retained: all three run at the same rate and ignore it
while deselected, so the separation costs data lines and selects rather
than a second clock domain.

##### The framebuffer is not a coherency domain

**The consumer does not care**, and that single fact carries more of this
design than it first appears.

**A stale read differs in *category*, not degree:**

| | stale read means |
|---|---|
| main memory | wrong computation — silent corruption, wrong results, possibly a crash |
| **framebuffer** | **one frame shows old pixels** — a tear, gone on the next refresh |

**So scanout neither snoops nor flushes.** No comparator on the hot path,
no stall waiting for a buffer to drain, and **the real-time deadline is
protected structurally rather than by careful arbitration.** The write
buffer is free to be as lazy as it likes — which is precisely what makes
it coalesce well.

**This is the period contract, not a compromise.** Video hardware never
promised coherency. That is why `while (inp(0x3DA) & 8);` exists — a DOS
programmer waits for vertical retrace because synchronisation was always
the software's job. **A program that wrote during active scanout tore on
a real VGA, and will tear here, for the same reason.** Matching that is
authenticity rather than laziness, and any driver writer already knows
the rule: **get the frame into memory before scanout reaches it, or own
the result.**

**The boundary is precise: coherency is required where data is *computed
on*, not where it is *displayed*.** A host read-modify-write — XOR
sprites, masked blits — is arithmetic and must see written data. That is
why host reads flush the buffer and scanout reads bypass it.

> **And it is what made the single-master architecture possible.** Had the
> framebuffer required coherency with the CPU's view of main memory,
> giving video its own memory would have created a coherency problem
> spanning two controllers. **Because it does not, the separation is
> free** — the whole private-video-memory decision rests on this property.

##### Clock it at 66 MHz — CPUCLK × 2, the SDRAM domain

**Ganged ×8 delivers one full byte per data clock.** At **66 MHz that is
~62 MB/s effective**, which meets the scanout requirement with margin —
and 66 MHz is not chosen for the arithmetic. **It is CPUCLK × 2, the
clock the SDRAM already runs on.**

- **One memory clock domain** for both memories, rather than an 84 MHz
  oddball beside a 66 MHz one.
- **Fixed phase relationship to the CPU**, which is the property the
  memory section already insists on rather than treating clocks as
  independent.
- **Well below the part's 144 MHz ceiling**, so the interface is run
  conservatively — good for signal integrity, and at 66 Mb/s per pin it
  is trivially inside 1× gearing on **any** bank.

**Burst length is set by `tCEM`, not by the 1 K page.** Choose a
power-of-two that divides 1024 *and* fits inside `tCEM`, and the wrap
boundary is never reached — the wrap behaviour becomes unreachable by
construction rather than something to work around.

| burst | clocks + 14 overhead | duration | verdict | effective |
|---:|---:|---:|---|---:|
| 256 B | 526 | 7.97 µs | at the 8 µs limit — no margin | 64.2 MB/s |
| **128 B** | 270 | 4.09 µs | **safe at 85 °C — chosen** | **62.6 MB/s** |
| 64 B | 142 | 2.15 µs | safe at 105 °C as well | 59.5 MB/s |

**The result is robust: 59–64 MB/s across the whole practical range**, so
the ~60 MB/s planning figure holds whichever burst size and temperature
grade are finally used. **Take 64 B if the 105 °C grade is fitted** — it
costs 5% and removes a thermal dependency.

**Burst boundaries double as preemption points.** `CS` rises every 128
bytes regardless, so pending CPU writes are slotted between scanout
bursts with no interrupt logic and no partial-burst abort. At 640×480,
scanout occupies ~31% of the device, leaving room for roughly two write
bursts between each scanout burst.

##### Decided: a write-combining buffer. Open: its width

**The buffer is wanted** — writes must be absorbed while scanout is
active, and the arithmetic below shows there is no tolerable alternative.
**What waits on the part survey is one number: the line width.**

> **Design rule: line size ≡ burst length.** They cannot be chosen
> independently.
>
> - **Line larger than burst** — a full line needs several bursts,
>   introducing partial flushes and the bookkeeping that goes with them.
> - **Line smaller than burst** — a burst cannot be filled from one line,
>   so several must be gathered, wasting burst capacity on every flush.
>
> **So the survey does not merely inform this buffer, it dimensions it.**
> That is why the constant is worth getting right before the RTL is
> written rather than after.

**Why something is needed.** The PSRAM is half-duplex, so a CPU write
arriving mid-burst waits for the burst to finish — **~4 µs at 128 bytes,
about 135 CPU clocks at 33 MHz, on every write.** That is not survivable
for software that draws directly to video memory, which is all of it.

**Sketch: a write-combining buffer whose line size is the burst size.**

```
4 lines × <burst> bytes, each with { base address, dirty mask }
  CPU write  → hits an open line, or allocates one
  line full  → flush as a single burst write
  no line    → evict LRU
```

Matching line to burst is the point: `REP STOSD`, the common DOS
full-screen fill, then coalesces into whole-burst writes rather than
dozens of separate command and address sequences.

**Cost is negligible** — one `DP16KD` covers data and tags, **1 block of
208**, so it does not meaningfully compete with the L2.

**Depth is invariant under the survey; only width moves.** A 486 at
33 MHz sustains a 32-bit write every 2 clocks — ~60 ns, ~66 MB/s — so the
writes arriving during one scanout burst are:

| burst | duration | writes arriving | bytes | lines needed |
|---:|---:|---:|---:|---:|
| 64 B | 2.15 µs | ~36 | 142 | **2.2** |
| 128 B | 4.09 µs | ~68 | 270 | **2.1** |

**Both land at ~2.2 lines**, because accumulation and burst duration
scale together. **Four lines is comfortable either way**, so the depth
decision does not depend on the survey outcome — only the width does.

**Two coherency cases, wanting different answers:**

- **Scanout need not snoop it.** A pixel one frame late is invisible, and
  is what period hardware did anyway. Do not build that path.
- **CPU reads must see buffered writes** — period software does
  read-modify-write on video memory for XOR sprites and masked blits.
  Simplest correct rule: **a CPU read of the framebuffer region flushes
  the buffer first.** Reads there are far rarer than writes.

**What it does not fix**, and should not be expected to: sustained
full-rate writing still throttles. Scanout takes ~31% of the device at
640×480, leaving ~43 MB/s for writes against a 486's ~66 MB/s of
back-to-back `STOSD`. A full-screen clear therefore runs ~35% slower than
the CPU could manage alone — **bounded and predictable, versus 135-clock
stalls on every write without it.**

##### Open — survey QSPI PSRAMs for a lowest common denominator

**Do not design against one vendor's part.** The controller should be
portable across manufacturers, so the constants must be the worst case
across a candidate set rather than the best case of a favourite.

- [ ] **Survey the field** — AP Memory `APS6404L`, Espressif
      `ESP-PSRAM64`, ISSI serial PSRAM, and the Chinese second sources —
      and record, per part: **page size, `tCEM` by temperature grade, max
      QPI clock, wrap behaviour, dummy-cycle count, command set, and
      supply voltage.**
- [ ] **Take the minimum of each**, not the typical.
- [ ] **Parameterise the controller** — burst length, dummy cycles, page
      size and the QPI-entry sequence belong in parameters or a small
      init table, **not hardcoded in the state machine.** A different part
      should be a constant change, not a redesign. Vendor initialisation
      sequences differ more than anything else.

**Preliminary — the LCD looks close to free.** Taking the worst values
already seen (1 K page, `tCEM` 3 µs at 105 °C):

| | value | result at 66 MHz |
|---|---|---|
| safe burst under 3 µs `tCEM` | **64 B** | 142 clocks, 2.15 µs |
| effective throughput | | **59.5 MB/s** |
| against the 128 B best case | | 62.6 MB/s — **a 5% difference** |

**So designing for the lowest common denominator costs about 5% and still
meets the ~60 MB/s target.** The survey is therefore expected to move a
constant rather than the architecture — but it should be run before the
constant is fixed, not after.

##### The separate chip selects are the useful part

The two PSRAMs have **independent selects**, not a shared one, and that
single extra pin buys a choice the RTL can make at runtime:

- **Assert both together — ganged ×8.** 8 bits per clock, **~60 MB/s
  streamed**, which is the scanout figure everything above is designed
  around.
- **Assert them separately — two independent ×4 devices.** ~30 MB/s each,
  but **scanout and CPU writes can then proceed concurrently** on
  different devices.

That second mode **eliminates the half-duplex contention outright** rather
than buffering around it: video streams buffer A from one device while
the CPU draws buffer B on the other, and they swap at vblank. Double
buffering falls out of the wiring instead of costing bandwidth.

30 MB/s streamed still covers 640×480×8 (18.4 average) comfortably. So the
choice is **bandwidth or concurrency, decided in the bitstream** — and
both remain available on the same board.

**~60 MB/s streamed.** Design against the *average* rate, not the peak:
active video is only ~73% of frame time, and the line buffer absorbs the
blanking gaps.

| mode, 8 bpp | peak | **streamed average** | at 60 MB/s |
|---|---:|---:|---|
| 640×480 @60 | 25.2 | **18.4** | 31% |
| 800×600 @60 | 40.0 | **28.8** | 48% |
| 1024×768 @60 | 65.0 | **47.2** | 79% |
| 800×600 @60, 16 bpp | 80.0 | **57.6** | 96% — the ceiling |

**Two consequences beyond the bandwidth.**

- **It largely dissolves the write-combining problem**, which was the real
  objection to a single device. At ~31% utilisation for 640×480 there is
  two-thirds of the device free for CPU framebuffer writes, turning a hard
  real-time buffering problem into an ordinary one.
- **It moves FPGA video from "DOS modes only" to genuine SVGA**, which
  changes what the CL-GD5428 mezzanine is for — from *the* video answer to
  a period-authenticity option.

**Capacity is irrelevant and free:** 16 MB against the **2 MiB** the
framebuffer actually wants, which is itself period-correct — GD5428-era
cards shipped 512 KB to 2 MB.

- [ ] **Budget consequence: 198 → 202, leaving 3 spare.** That is
      uncomfortably tight, so this **effectively decides the `A24-A31`
      pin-saver** (194, 11 spare) — which this document already argues for
      on other grounds, since 16 MB is the SX-class ceiling and makes the
      CPU variants agree rather than diverge.
- [ ] **Length-match the two devices' data lines to each other.** Shared
      clock, SDR at 84 MHz — not the strict matching of a DDR bus, but
      they are not unrelated nets either.

**Preferred: QSPI PSRAM as the video memory, with a BRAM line buffer.**
8 MB is far more than any DOS mode needs — a period GD5428 shipped with
512 KB — and it leaves the BRAM for the L2 cache, which is what hides
SDRAM latency from the CPU. **Spending 64% of BRAM on a framebuffer would
damage the CPU path to solve a video problem.**

**Scaling does not change this.** The framebuffer is read at *guest*
resolution and upscaled on the fly into the TMDS path, so memory traffic
is set by the guest's mode, not the output mode. **Even if the display
gate forces 720p output, memory traffic stays at 640×480 rates** — which
decouples this decision from G2's outcome.

**The resulting architecture is single-master everywhere:**

- **SDRAM** — CPU only. Latency-optimised. One master, simple controller.
- **QSPI PSRAM** — video only. Sequential scanout, plus CPU writes through
  a combining buffer.
- **BRAM** — L2 for the CPU, line buffer for video.
- **HyperRAM** — **dropped.** No workload fits it: the CPU is
  latency-bound and HyperRAM is high-latency and narrow, while video is
  served by the QSPI pair. A part with no job is not a hedge, and its
  BGA25 would have had to be populated on every prototype to be testable
  at all. Removing it frees 12 pins and leaves the ECP5 as the board's
  only BGA.

- [ ] **Design the write-combining buffer.** This is the real work, not
      the bandwidth. QSPI PSRAM is half-duplex, so an uncombined CPU write
      waits for an in-flight burst — ~6 µs at 84 MHz, roughly 200 wait
      states at 33 MHz. Period software writes directly to video memory,
      so this determines whether it feels like a 486 or like treacle.
- [ ] **Confirm the 84 MHz linear-burst limit** on the specific part. x4
      linear burst crossing page boundaries is limited to 84 MHz; the
      133 MHz figure is for page-bounded or x1 access. **The lower number
      is the one scanout hits.**
- [ ] **Accept the ceiling: 640×480×8 bpp.** 800×600 needs 40 MB/s and
      does not fit. If FPGA video must exceed 640×480, this resolution
      fails and shared memory returns — with all of the above.

- [ ] Decide whether video gets a dedicated channel. **This is a
      pin-assignment decision and must be made before layout freezes**,
      alongside the other items in that class.
- [ ] With that decided, the memory subsystem can be specified against
      the CPU alone — which is where the latency and four-word-ceiling
      reasoning applies cleanly, rather than being contested by scanout
      bandwidth.

### Two video paths, and they are alternatives worth keeping distinct

| | on-board FPGA video | CL-GD5428 on the local bus |
|---|---|---|
| output | HDMI (fake TMDS from the ECP5) | analogue RGB to a CRT |
| framebuffer | external DRAM, shared | the chip's own DRAM |
| compatibility | as good as the core written | **exact, it is the silicon** |
| FPGA cost | a Cirrus-compatible core | none |
| supply | none | a 1990s part, NOS or salvage |

**If a real GD5428 is fitted, the FPGA does not need a Cirrus core at
all** — which reverses the note recorded earlier that the
Cirrus-compatible core is "load-bearing rather than convenient". It is
load-bearing only for the HDMI path. Whether both paths coexist is
undecided.

Three things to check early:

- [ ] **Bus width against the socket.** VLB *is* the 486 32-bit local
      bus. A 386SX has a 16-bit data bus, so a VLB-attached GD5428
      cannot serve it. The GD542x family also supports a 16-bit ISA-style
      interface, so a dual-socket board may need the chip strapped
      differently per socket — or the VLB path may be 486-only.
- [ ] **Bus arbitration.** The chipset must *not* claim `0x3c0-0x3df`
      or the `0xa0000-0xbffff` aperture when the real chip is present,
      and must let it respond directly.
- [ ] **Supply risk.** A discontinued 1990s part in a product aimed at
      enthusiasts is a sourcing constraint on build volume, and cuts
      against "does not want to spend hundreds on nostalgia" if the part
      is scarce.

**Simulation consequence.** Real silicon cannot be Verilated. The
co-simulation would keep a software Cirrus model for the FPGA path,
and the GD5428 path would be validated on hardware only — the same
class of gap as bus timing, and worth recording as accepted rather than
discovered later.

### Direction: be register-compatible with QEMU's Cirrus model

**This applies to the FPGA video path.** It is unnecessary if a real
GD5428 is fitted, and it is exactly what that chip implements — so the
register list below doubles as the compatibility target either way.

The payoff is that **the video BIOS arrives as a finished package** —
SeaVGABIOS's `clext.c` — rather than being written. QEMU's `isapc`
already loads `vgabios-cirrus.bin`, so ISA Cirrus is a supported
combination, not an improvisation.

**The compatibility surface needed to inherit the BIOS is bounded, and
much smaller than a full Cirrus clone.** Read out of `clext.c`:

| | registers |
|---|---|
| detection | sequencer `0x06`: write `0x92`, read back `0x12` |
| memory size | sequencer `0x0f`, bits 4:3 (and bit 7 for 4 MiB) |
| VCLK / mode | sequencer `0x0b-0x0e`, `0x1b-0x1e`, `0x07`, `0x12`, `0x13`, `0x17`, `0x0a` |
| banking / offset | graphics controller `0x09`, `0x0a`, `0x0b` |
| extended CRTC | `0x1a`, `0x1b`, `0x1d` |
| colour depth | the hidden DAC register (`0x3c6` quad-read sequence) |
| BitBLT | `grdc 0x31` — **reset only** |

Plus a standard VGA core underneath, which `stdvga.c` drives.

**The accelerator is not required.** SeaVGABIOS touches BitBLT exactly
once, to reset it at init, and never issues a blit. That removes the
single most expensive block from the critical path.

The inherited mode set is 640x480, 800x600 and 1024x768 at 8/15/16/24
bpp. Note 1024x768x24 is 2.25 MiB, which is consistent with the
framebuffer living in external DRAM.

Honest limit: this buys **mode setting and VESA VBE**, not accelerated
software. DOS titles and Windows drivers that drive Cirrus BitBLT
directly would need the engine. Most DOS SVGA software uses VBE with
banked or linear framebuffer writes and would be fine.

- [ ] Decide which Cirrus the model claims to be, and make sequencer
      `0x0f` report a size that matches the DRAM actually allocated.
- [ ] **Place `vgabios-cirrus.bin` at `0xc0000`.** With no PCI there is
      no expansion-ROM BAR, so the BIOS finds it by scanning — which is
      exactly what `isapc` does (`Running option rom at c000:0003`).
      That makes the VGA BIOS another reset-vector-placed image.
- [ ] **Decide whether BitBLT and the hardware cursor are in scope.**

      > **Correction to an earlier claim.** It was argued that neither is
      > needed *because SeaBIOS does nothing with them*. **The premise is
      > true and the reasoning is wrong** — firmware was never the
      > consumer that matters.

      **Verified from source:**

      | | finding |
      |---|---|
      | SeaVGABIOS `clext.c` | only **resets** the blitter at init (`GR31 ← 0x04, 0x00`); never draws with it |
      | SeaVGABIOS cursor | uses **`swcursor.c`**, a software cursor XOR'd onto the framebuffer |
      | QEMU `cirrus_vga.c` | **implements both**; the blitter is roughly a third of the file — ROP tables, pattern fill, colour expand, CPU→video and video→video |

      **The real consumer is Windows 3.x with the Cirrus driver** — window
      blits, and the hardware cursor for the mouse pointer. **A 486 with
      32 MB and SVGA is a natural Windows 3.11 machine**, so this is not a
      hypothetical. DOS applications overwhelmingly write the framebuffer
      directly and never touch the blitter.

      **So the question is really: is Windows in scope?** And the two video
      paths answer it differently:

      | path | blitter |
      |---|---|
      | **CL-GD5428 on the mezzanine** | **in real silicon — nothing to implement** |
      | **FPGA video**, if it claims to be a Cirrus | **~a third of QEMU's model, in RTL** |

      > **If BitBLT or the hardware cursor are ever built, build them on
      > the shadow.** *Tinker-later, not now.*
      >
      > A blitter operating on the **cacheable SDRAM master copy** is a
      > far smaller problem than one operating on PSRAM: reads hit L2,
      > writes are page hits, and **the blitter never touches PSRAM at
      > all** — the existing dirty-tile DMA propagates the result exactly
      > as it does for CPU drawing. Same for a hardware cursor, which is
      > composited into the shadow.
      >
      > **So acceleration reduces to "a second writer of the shadow"**,
      > reusing the whole path already designed rather than needing a
      > parallel one. And the register interface stays **era-correct**, so
      > period drivers drive it unmodified.
      >
      > **Nice-to-have. Not required, not gating, and it needs no hardware
      > changes** — it is entirely RTL on the shadow side of the DMA, so
      > nothing about it constrains the board, the pin budget or the
      > prototype. Recorded only so that if the blitter is ever attempted,
      > it is attempted on the right side of the DMA.

      **There is a clean way out.** SeaVGABIOS also ships **`bochsvga`** —
      plain VGA plus VBE with a linear framebuffer, no acceleration.
      That covers **every DOS mode** and sidesteps Cirrus emulation
      entirely. **Cirrus acceleration then lives only on the mezzanine,
      in the real chip, for anyone who wants Windows.**

      **Cost measured, not estimated.** ao486's full VGA
      (`rtl/soc/vga.v`, 1721 lines — CRTC, sequencer, graphics and
      attribute controllers, chain-4, planar read/write modes, colour
      compare, text mode) synthesised for ECP5 with Yosys:

      | | |
      |---|---:|
      | `LUT4` | **2310** |
      | `CCU2C` / `PFUMX` / `L6MUX21` | 266 / 596 / 146 |
      | `TRELLIS_FF` | 1084 |
      | dual-port RAMs (→ `DP16KD`) | 6 |

      **Add ~150–250 LUT4 for DISPI** — eleven registers, a decode and
      mode select — so **call the target ~2500–2700 LUT4.**

      > **Against ~84 K LUTs on the 85F that is under 4%. Video is not
      > what sizes the FPGA** — the CPU bus, memory controllers, cache and
      > soft core are. Useful for the density question still open
      > elsewhere: **FPGA video is not a reason to need the 85F.**

      **BRAM is the real cost, and it is negotiable.** ao486 keeps all
      four 64 KB planes on-chip — **256 KB against the 85F's 468 KB**,
      which collides directly with the L2 budget. With QSPI PSRAM as the
      framebuffer, **only the legacy 64 KB window need stay on-chip** and
      linear modes live in PSRAM, which changes that figure substantially.

      **Conclusion: the video core sits entirely in the FPGA**, and stays
      there until something demands better. The `CL-GD5428` mezzanine
      remains an **escape hatch rather than a plan.**

      **The field was surveyed before choosing.** Every freely available
      model was examined, and `bochsvga` survives on merit rather than by
      default:

      | model | verdict |
      |---|---|
      | **Bochs VBE / `bochsvga`** | **chosen.** 11 registers, 2 I/O ports, VESA LFB, DOS-complete, Win9x drivers exist |
      | **Cirrus `CL-GD54xx`** | period-correct and the original target, but the blitter is ~⅓ of QEMU's model in RTL — **deferred, not rejected** |
      | **QXL** | **rejected** — PCI-only, a SPICE shim rather than a controller, no DOS or Win9x drivers |
      | real `CL-GD5428` on the mezzanine | still available, in **real silicon**, if period authenticity is wanted |

      **The intended arc, recorded so the sequence is deliberate rather
      than reactive:**

      1. **Now — `bochsvga`.** Smallest thing that is DOS-complete and
         drives Windows unaccelerated.
      2. **When features are needed — the dual-framebuffer model.** Shadow
         in cacheable SDRAM, dirty-tile DMA to PSRAM.
      3. **Then — BLIT and cursor on the shadow**, and with them the
         **pivot to the Cirrus model.**

      > **Cirrus is *not* a superset of Bochs VBE — checked.** They are
      > two different extension schemes over a shared VGA core:
      >
      > | | extension mechanism |
      > |---|---|
      > | Bochs VBE | **separate ports** `0x1CE`/`0x1CF`, own 11-register space |
      > | Cirrus | **the existing VGA ports** — `0x3C4/5` sequencer, `0x3CE/F` graphics — with extended indices |
      >
      > QEMU's Cirrus registers only `0x3B0–0x3DF` and references DISPI
      > nowhere. **So the pivot replaces the register layer rather than
      > extending it.**
      >
      > **What carries over is the expensive part**: legacy VGA decode,
      > framebuffer, scanout, palette, banking window, and the entire
      > shadow / DMA / write-buffer infrastructure, which lives below the
      > register layer.
      >
      > **What does not: mode setting — and it is a bigger step than the
      > blitter.** Bochs VBE is *"tell it the resolution"*; **Cirrus is
      > *"program the CRTC yourself"***, which is what the `ccrtc_*` tables
      > in `clext.c` are doing. Mitigation: **pattern-match programmed CRTC
      > values against known modes** rather than implementing a general
      > CRTC — appropriate anyway, since output is a fixed HDMI mode with
      > scaling.

      > **And weigh it against the design philosophy, not only against
      > effort.** *"Program the CRTC yourself"* is the **old
      > way**; Bochs VBE's *"tell it the resolution"* is the new one.
      > Adopting Cirrus to gain a blitter means **taking a step backwards
      > on the axis this project is explicitly organised around** —
      > *period where it has to be, modern where it can be.* That cost is
      > real and belongs in the decision, not just the RTL estimate.
      >
      > **But the CRTC question may already be latent in the DOS
      > requirement.** Period software does not only set modes through
      > `INT 10h`: **Mode X and the tweaked modes reprogram the CRTC
      > directly** — 320×240, unchained VGA, split-screen and panning
      > tricks. Doom and much of the demoscene depend on it.
      >
      > **Resolved — and it was a false choice.** `bochsvga` is not *"the
      > DISPI interface instead of VGA"*. It is **the complete legacy VGA
      > core — CRTC, sequencer, chain-4, planar modes — *plus* DISPI**
      > bolted on for high resolutions. That is exactly why **Doom runs
      > under `-vga std`**: Mode Y's unchaining and CRTC pokes are served
      > by the VGA core underneath, not by the VBE extension.
      >
      > **So the CRTC is owed by the `bochsvga` path itself**, the moment
      > DOS compatibility is in scope. Cirrus never introduced it.
      >
      > **What Cirrus actually adds on this axis is incremental**:
      > *extended* CRTC registers (`CR19`/`CR1A`/`CR1B`, addressing
      > overflow) on top of a CRTC that already exists. **The design-philosophy
      > objection therefore largely evaporates** — the step was taken when
      > DOS compatibility was accepted, and it was taken knowingly.

      > **Which is where the project wanted to be from the start.** The
      > Cirrus path was never abandoned — it was **deferred until the
      > infrastructure that makes it cheap exists.** Building the shadow
      > first turns the blitter from "a third of QEMU's model against
      > PSRAM" into "a second writer of cacheable SDRAM." **Same
      > destination, reached at a fraction of the cost, and nothing along
      > the way is thrown out.**

      - [x] **DECIDED — `bochsvga` is the video model.** VESA VBE with a
            linear framebuffer, DOS-complete, eleven registers behind two
            I/O ports. **Windows 9x works via `vmdisp9x`/VBEMP**,
            unaccelerated. The blitter question does not arise.

            **The Cirrus model stays available for blit and cursor
            support later, if and when it is deemed necessary** — built on
            the SDRAM shadow, per the note above. **Nothing gates on it**,
            and it needs no hardware change, so it can be taken up at any
            point or never.

            *Costs one `#define`* — see below.

      > **`bochsvga` needs one `#define` changed from stock.** Its LFB
      > address is compile-time:
      >
      > ```c
      > u32 lfb_addr = VBE_DISPI_LFB_PHYSICAL_ADDRESS;   // 0xE0000000
      > if (CONFIG_VGA_PCI && bdf >= 0) { ... }          // PCI BAR only
      > SET_VGA(VBE_framebuffer, lfb_addr);
      > ```
      >
      > With no PCI the constant stands. **Drivers take `PhysBasePtr` from
      > the VBE mode-info block, so they follow the VGA BIOS** — only
      > `VBE_DISPI_LFB_PHYSICAL_ADDRESS` in `vgasrc/bochsvga.h` needs
      > changing, not the drivers.
      >
      > **What it costs depends on where it is pointed:**
      >
      > | LFB | address bus | memory hole |
      > |---|---|---|
      > | stock `0xE0000000` | **full 32-bit** | none — sits above RAM |
      > | patched inside 16 MB | **pin-saver survives** | **hole carved from RAM** |
      >
      > **Against the stated goal of unmodified firmware this is a fork**,
      > though about the smallest one available.

      > **QXL — inspected, rejected.** Three independent
      > disqualifications: it is **PCI-only** (five BARs, config space,
      > PCI interrupts) and this machine has no PCI; it is a **SPICE
      > shim rather than a display controller**, calling
      > `spice_qxl_*` to hand commands to a server that does the actual
      > rendering; and it has **no DOS or Win9x drivers** — a DOS guest
      > falls back to plain VGA even under QEMU. Category-mismatched
      > rather than merely unsuitable.
      >
      > **Worth keeping from it: the ring-buffer model.** The guest writes
      > commands into a ring in shared memory and the device consumes them
      > asynchronously, so **the CPU queues work instead of stalling on
      > it.** That is the right shape if acceleration is ever *offloaded*
      > — to the ESP32 or a soft core — rather than implemented in RTL.
      >
      > **The guest-driver requirement is exclusive; the device is not.**
      > QXL embeds `VGACommonState` — **the same VGA core `-vga std`
      > uses** — so QXL is, structurally, *bochs VGA plus a ring offload*.
      > A ring could therefore be **added on top later** exactly as QXL
      > builds it on top of VGA. What stays exclusive is the driver:
      > **no period software will ever submit to a ring**, so it buys
      > nothing for the target workload.
      >
      > **DECIDED — parked in favour of the write path.** The only
      > conceivable consumer is Win 3.11 or 9x, and those already work
      > unaccelerated. **Effort goes instead to LFB support in `bochsvga`
      > and a strong write-combining buffer in the VGA memory core**,
      > because **both target paths are write-bound**:
      >
      > | path | bottleneck |
      > |---|---|
      > | DOS | writes the framebuffer directly |
      > | Windows, unaccelerated driver | CPU blits — memcpy to framebuffer |
      > | ring buffer | **neither — no period driver exists to use it** |
      >
      > **The write buffer is leverage on three questions at once:** DOS
      > speed, Windows tolerability, and — by making unaccelerated Windows
      > acceptable — **it weakens the case for the Cirrus blitter too.**
      > A ring is leverage on none of them.

      > **PHASING — stub now, implement during optimisation.**
      >
      > | phase | video memory path | cost |
      > |---|---|---|
      > | **1 — bring-up** | **CPU reads and writes PSRAM directly** | **slow, and accepted.** Correct, simple, and enough to get pixels on a screen |
      > | **2 — optimisation** | shadow in cacheable SDRAM, dirty-tile DMA | fast; added when schedule allows |
      >
      > **Design the stub in phase 1**: the framebuffer aperture decode
      > should be **switchable between PSRAM-direct and shadow**, and the
      > DMA should have its hook present but unpopulated. **No hardware
      > impact either way** — both paths use the same pins, so this gates
      > nothing on the board.
      >
      > **Two notes so phase 2 costs no rework:**
      >
      > - **"Host reads always come from main memory" is a phase-2
      >   property, not a day-one rule.** In phase 1 host reads do hit
      >   PSRAM, slowly.
      > - **So the write buffer's host-read flush rule is needed in phase
      >   1** and simply **stops being exercised in phase 2.** Implement
      >   it; it becomes dead code rather than something to remove.

      **Idea worth exploring — shadow framebuffer in SDRAM, DMA to
      PSRAM.** For Windows specifically: **let the CPU write the
      framebuffer into main memory**, and have a background DMA move dirty
      regions into the QSPI PSRAM.

      **Both sides get the memory that suits them:**

      | | |
      |---|---|
      | CPU writes | land in **SDRAM — ~30 ns page hits, 133 MB/s, cacheable** — instead of contended half-duplex PSRAM |
      | DMA writes | **perfectly sequential**, so every burst is full and command overhead amortises away, where scattered CPU writes pay it constantly |
      | PSRAM | reduced to what it is best at: **write-in-bulk, read-continuously** |

      **And transforms become cacheable — which is the strongest argument
      of the three.** Unaccelerated blitting *is* read-modify-write: a ROP
      reads the destination, combines, writes back. Every such read on the
      direct path is a **half-duplex PSRAM read contending with scanout**,
      microseconds each, **and it forces a write-buffer flush besides.**
      In a cacheable SDRAM shadow those reads hit **L2 at ~1 cycle.**

      | operation | direct to PSRAM | shadow in SDRAM |
      |---|---|---|
      | write | contended, half-duplex | ~30 ns page hit, 133 MB/s |
      | **read (ROP, sprite mask, palette)** | **µs — and flushes the write buffer** | **L2 hit, ~1 cycle** |
      | scanout | unchanged | unchanged |

      **So the shadow does not merely make writes faster — it makes
      transforms possible at all**, and it **removes the host-read flush
      penalty** recorded against the PSRAM write buffer, because the CPU
      stops reading PSRAM entirely.

      > **This is what `PCD`/`PWT` were retained for.** The shadow region
      > is marked cacheable while the PSRAM aperture stays uncached —
      > page-level cacheability driven outward by the CPU, which is
      > exactly the case those pins were kept to serve.

      **Dirty-region tracking is the enabler, not an optimisation.**

      | | |
      |---|---:|
      | write budget during blanking (4.57 ms @ 62 MB/s) | ~283 KB |
      | spare during active scan (12.1 ms @ ~13 MB/s) | ~157 KB |
      | **per frame** | **~440 KB** |
      | full 1024×768×8 frame | **768 KB** |

      **A whole frame does not fit in a frame's budget**, so blind copying
      fails. A tile-dirty bitmap is cheap — 64×64 tiles gives 192 bits —
      and typical GUI updates sit far inside the budget.

      > **INVARIANT: host reads always come from main memory.** The CPU
      > never reads PSRAM — there is no path for it to. That single rule
      > collapses several problems rather than mitigating them:
      >
      > - **The host-read flush rule is deleted, not reduced.** It was
      >   recorded against the PSRAM write buffer as a real cost; with this
      >   invariant no host read can reach PSRAM, so the rule is vacuous.
      > - **The PSRAM sees exactly two access patterns** — sequential DMA
      >   writes, sequential scanout reads. **No read arbitration, no
      >   snoop, no flush logic.** Two masters with fixed, non-overlapping
      >   roles.
      > - **SDRAM is authoritative; PSRAM is derived state.** Nothing ever
      >   reads back from it, so a corrupted tile **self-heals on the next
      >   dirty update and cannot propagate** into the machine.
      >
      > It also sharpens the earlier principle: the framebuffer is not a
      > coherency domain because **there is nothing left to be coherent
      > with.**

      **Refined — two copies, synchronised at two different rates.**

      | | |
      |---|---|
      | **master copy** | **SDRAM, cacheable.** All drawing and all transforms happen here |
      | **scanout copy** | **PSRAM.** Written only by DMA, read only by scanout |
      | **full sync** | **once per mode switch** — 768 KB, ~12 ms, during a transition where nothing is being watched |
      | **incremental** | **dirty tiles via DMA during blanking**, steady state |

      **That split is what makes the arithmetic work.** The ~440 KB/frame
      budget only ever has to carry *dirty tiles*, never a whole frame —
      the whole-frame copy happens at mode switch where latency is
      invisible. A full-screen repaint spills to two frames, and even that
      beats the CPU writing 768 KB into PSRAM directly.

      **The memory is already paid for:** the second rank is the
      `A13/CS1` pin already decided — **32 MB, of which a 2 MiB shadow is
      noise.**

      > **This does not break the single-master rule, and it is worth
      > saying why.** SDRAM gains a second reader in the DMA, which looks
      > like the thing the private-video-memory decision existed to
      > prevent. It is not: **that argument was about a master with a hard
      > real-time deadline.** Scanout cannot wait; **this DMA always can.**
      > It has no deadline, reads sequentially in page-hit bursts, and
      > yields to the CPU on demand — so it adds no latency *variance* to
      > the path the design is organised around. **A polite second master,
      > not a competing one.**

      - [ ] **Mode-selectable, not global.** DOS software writes `0xA0000`
            and expects pixels now; a shadow path adds a frame of latency
            and would break per-scanline effects. **DOS keeps the direct
            path; Windows uses the shadow.**
      - [ ] **Coherency: the DMA must see the CPU's writes.** If the
            shadow region is cacheable and write-back, the DMA reads
            stale data. Either mark it **write-through**, or have the DMA
            snoop. Write-through to SDRAM is still far faster than
            anything the PSRAM path offers.
      - [ ] Costs: a DMA engine, the dirty bitmap, **double storage** (768
            KB in each memory — both have room), and one frame of latency.

      **This is the shadow-framebuffer/deferred-I/O pattern** that QEMU and
      Linux `fbdev` both use, which is a point in its favour: well-trodden,
      and it fits the machine's existing split of fast-writes memory versus
      stream-out memory.

      > **Note — DOS uses the linear framebuffer too.** It is not a
      > Linux-era feature. **VBE 2.0 introduced the LFB for DOS
      > extenders**, and protected-mode DOS software used it heavily.
      > The split is by vintage, not by operating system:
      >
      > | path | used by |
      > |---|---|
      > | 64 KB banked window at `0xA0000`, via `BANK` | **VBE 1.2, real-mode DOS** |
      > | linear framebuffer at a high address | **VBE 2.0, protected-mode DOS** (DOS4GW-era titles) |
      >
      > **Both are DOS paths, so the FPGA owes both.** Banking is not
      > legacy dead weight that can be skipped.

      **Windows 9x drivers for the Bochs adapter exist and are
      maintained** — [vmdisp9x](https://github.com/JHRobotics/vmdisp9x)
      (explicitly supports Bochs VBE and QEMU `std-vga`),
      [VBEMP 9x](https://bearwindows.zcm.com.au/vbe9x.htm),
      [boxv9x](https://github.com/phkelley/boxv9x), and `qemumini.drv`.
      **So choosing `bochsvga` does not cost Windows support.**

      **What it costs is acceleration.** Every one of those drivers is an
      unaccelerated framebuffer driver: each blit is a CPU memory copy.

      | | Windows | drawing |
      |---|---|---|
      | **Bochs VBE + VBEMP/vmdisp9x** | works, high res | **CPU-bound** — drags, scrolls, menus all memcpy |
      | **Cirrus, real GD5428 on mezzanine** | works | **blitter does it**, no CPU |
      | Cirrus emulated in FPGA | works | blitter in RTL |

      **Sharper here than on a PC**: a 640×480×8 full-screen blit is
      ~300 KB against a ~62 MB/s video path **shared with scanout**, so
      multiple milliseconds per operation with the CPU stalled throughout.

      **But keep perspective — Windows on a 486 was sluggish on real
      hardware.** Win 3.11 was the realistic target for this class of
      machine, and unaccelerated may be period-honest rather than a
      failure. **That judgement, not the RTL cost, is what should decide
      this.**

## Direction: sound synthesis is software

The SB16 / AdLib **register interface** is period-correct, like every
other front end. The **synthesis is not RTL** — it runs as software on a
microcontroller, with a modern output stage.

Two reasons, and the second is the stronger one:

- An OPL FM synthesiser in RTL is real work; in software it is a solved
  problem with a known-good implementation already in the fork
  (`fmopl.c`, plus `sb16.c`, `adlib.c`, `pcspk.c`).
- **The analogue quality of the original is a defect, not a
  characteristic worth reproducing.** A modern I2S DAC is strictly
  better on the axis nobody wants authenticity on.

Worth keeping the distinction clear: *synthesis accuracy* — the
chip-specific OPL behaviour that period music was composed around — is
worth preserving, and a well-tested software core preserves it better
than a fresh RTL implementation would. It is the **output stage** that
should be modern, not the sound.

- [ ] Which microcontroller hosts it is gated on the dividing line
      below. Sample delivery is continuous but low bandwidth, which
      argues for the ESP32; the SB16 register and DMA path is
      timing-coupled and argues for staying on-chip. The split may not
      fall at the same place as the device boundary.
- [ ] `i8257.c` (DMA) is needed for digital audio and is in the fork,
      unvendored so far.

## OPEN, and blocking: the dividing line between the two controllers

**This is the parent decision.** The arbitration questions below, and
the homes of the peripherals still to come (sound, USB, keyboard,
mouse), all wait on it. Nothing here is settled.

### Three tiers, not two

There are three places a peripheral can live, and the soft-core occupies
a genuinely useful middle:

| tier | latency to the guest bus | cost of complex logic |
|---|---|---|
| FPGA RTL | lowest | highest |
| **VexRiscv soft-core** | **on-chip, low** | **low — it is software** |
| ESP32 | off-chip, high | low |

The soft-core can host things too complex for RTL but too
timing-coupled for an off-chip round trip. That middle tier is what
makes the partitioning non-obvious.

### Split each peripheral at the register interface

Not "which tier owns this device" but "which tier owns the *front end*
and which owns the *back end*". The fork already does this consistently,
in three devices:

| device | front end (guest-visible) | back end |
|---|---|---|
| NE2000 | register model | tuntap / slirp / ESP32 WiFi |
| 8042 | register model + PS/2 queue | host keys / socket (`wifikbd.c`) / ESP32 |
| IDE | register model | file / controller-provided storage |

`i8042.c` already carries FreeRTOS mutexes on the PS/2 queue precisely
so another task can inject events. The pattern is load-bearing upstream,
not incidental.

**The front end must stay period-correct and low-latency** whichever
tier runs it — that is what the hard 386SX/486DX in the socket requires.
The back end can live anywhere.

### What decides it

- **How tightly the guest is coupled to device timing.** A guest
  spinning on a status register cannot tolerate an off-chip round trip;
  an event-driven device at human timescale can.
- **Bandwidth.** The `0xa0000` aperture is the extreme case.
- **Implementation-cost asymmetry.** USB host stacks, TCP/IP,
  filesystems and FM synthesis are far cheaper in software. Bus
  protocol timing, DMA and scanout are far cheaper in RTL.

### First-pass reading, to be confirmed rather than assumed

- **Video is the one that cannot go off-chip.** Aperture bandwidth and
  scanout timing rule it out. RTL plus framebuffer memory.
- **Sound** splits: the SB16 register interface and DMA are
  timing-coupled and belong on-chip; FM synthesis does not (`fmopl.c`
  exists). Output can be ESP32 I2S or FPGA-side. Note `sb16.c`,
  `adlib.c`, `fmopl.c`, `pcspk.c` and `i8257.c` are all in the fork.
- **Keyboard and mouse**: front end is already vendored and running.
  Only the event source moves.
- **USB is not a guest-visible device at all for DOS.** It is a back-end
  transport for HID. No USB controller needs modelling — a real scope
  saving, and worth stating so it does not get built by reflex.

### The testbench can answer this empirically

Rather than deciding by intuition: the co-simulation already counts bus
transactions per port, so it can measure how tightly a guest actually
polls each device during a real workload. That is the evidence the
partitioning wants, and it is one of the things the rig exists for.

- [ ] Determine the dividing line. Until then the arbitration items
      below stay open on purpose.

## Design goal: mini-ITX form factor

The motherboard targets **mini-ITX (170 x 170 mm)**, so it lives in a
modern small-footprint case. Not period-correct, deliberately — a
machine that is a burden to keep set up is a machine that does not get
used.

**This is not a new constraint so much as a second justification for the
architecture already chosen.** Every "modern back end" decision also
buys board area:

| decision | area reclaimed |
|---|---|
| WiFi via ESP32 | no RJ45 (tall) or magnetics |
| ESP32 block storage | no drive connectors or bays |
| NTP time | no coin cell or holder |
| HDMI from the FPGA | no VGA card, no slot |
| peripherals as FPGA logic | no discrete 8259/8254/8042/NE2000 packages |

### The tension worth resolving: a physical VLB slot does not fit

Approximate edge budget against 170 mm:

| | length |
|---|---|
| 16-bit ISA connector (98-pin) | ~129 mm |
| VLB extension (116-pin), inline | ~51 mm |
| **ISA + VLB together** | **~180 mm — exceeds one board edge** |
| short ISA card | ~170 mm |
| full-length ISA card | ~333 mm |

A VLB slot is an ISA connector with the VLB connector inline behind it,
and the pair is longer than a mini-ITX board edge. Even a plain 16-bit
ISA slot would consume most of one edge, and the card would overhang
the board and miss the single rear slot opening a mini-ITX case
provides.

So **mini-ITX and a real VLB video card are close to mutually
exclusive**, which points at on-board HDMI being not merely preferable
but the only option that fits — and makes the Cirrus-compatible core
load-bearing rather than a convenience.

The "(kinda)" in "VESA local bus (kinda) video" may already account for
this: a VLB-*like* on-board local bus to the FPGA sidesteps the geometry
entirely, since it needs no connector. Recorded as a question rather
than an assumption.

**Resolved: on-board, not a slot.** The VLB route, if taken, is a
**Cirrus Logic CL-GD5428 down on the board**, connected directly to the
x86 local bus. No connector, so the geometry problem above does not
arise.

### Other things the form factor decides

- [ ] **Power.** DC barrel with on-board regulation is cheaper and
      smaller than an ATX connector, and consistent with the BOM goal.
- [ ] **Rear I/O** within the 159 x 44.5 mm shield: HDMI, USB for HID,
      and little else — no RJ45, no VGA, no serial or parallel unless
      wanted for their own sake.
- [ ] **Socket area and height.** A 486 PGA socket plus heatsink is the
      tall, area-hungry item; a 386SX in PLCC or PQFP is neither. Worth
      checking against low-profile case lids before committing to a
      dual-socket board.
- [ ] ESP32 module placement and antenna keep-out.

## Design goal: reduced BOM at the motherboard layer

**Cost optimisation is a stated goal of the top-most (motherboard)
layer, and it means a reduced bill of materials.** Several decisions
below are consequences of it rather than independent choices, and should
be read that way.

Concretely, giving the ESP32 board controller time, configuration, block
storage and networking removes parts rather than adding software:

| function | discrete parts avoided |
|---|---|
| time / RTC | RTC chip, coin cell, battery holder |
| CMOS persistence | config EEPROM or SPI flash |
| networking | Ethernet MAC/PHY, magnetics, RJ45 |
| block storage | connector, media, and the drive itself |

The FPGA carries period-correct *register interfaces*; the parts those
interfaces used to imply do not have to exist. That is also why
peripherals are FPGA logic rather than discrete period chips — a
discrete 8254, 8259, 8042 and NE2000 is four packages and the board area
to route them, against LUTs and EBRs already paid for.

### Two controllers, not one

The machine has **two** microcontrollers, and they are not redundant in
the trivial sense — they sit in different places and fail differently:

| | ESP32 | VexRiscv soft-core |
|---|---|---|
| where | off-chip, on the board | inside the FPGA |
| reaches | NTP, network, block storage | whatever is on-chip |
| role | primary platform controller | **backup defaults / fallback** |
| BOM | one module | LUTs already paid for |

Concentrating time, configuration, storage and networking in the ESP32
would otherwise make it a **dependency for boot**: without it there is
no configuration, no time and no boot device. The soft-core answers
that. It is present whenever the FPGA is configured, so a fallback path
always exists, and it can serve *synthesised* defaults and run
diagnostics rather than only replaying a static image.

This costs no parts, which is consistent with the goal above.

**It also adds a role to the MCU.** It was a payload host — tiny386 is
one payload, chipset tests and diagnostics are others. It is now also
the fallback platform controller, and that role justifies the core
independently of any payload.

**The reset-exit vector's source is therefore "the platform
controller", either one.** `platform_cfg.c` already models it that way:
what is fixed is the content and the timing, not who supplies it or over
what bus. Nothing needs to change to accommodate this.

- [ ] **Settle the arbitration.** The natural shape is that the
      soft-core serves defaults immediately so the machine can always
      POST, and the ESP32's image overrides when it arrives — which
      answers the earlier "wait or proceed" question in favour of
      proceed. Confirm that, and decide what "catastrophic failure"
      detection looks like: a timeout, a heartbeat, or simply whichever
      controller writes last before reset-exit.
- [ ] Decide how much the fallback should provide. Enough to POST is one
      bar; enough to reach a diagnostic prompt without any off-chip part
      is a higher and more useful one.

## Direction: firmware configuration over fw_cfg, not CMOS

Configuration reaches the BIOS through the fw_cfg port interface
(`0x510`/`0x511`) rather than legacy RTC/CMOS registers. Implemented in
`sim/cosim/pc/fw_cfg.c` in [vexrv-cpu-oss](https://github.com/pawlex/vexrv-cpu-oss),
which has no counterpart in tiny386 — that
machine has no fw_cfg, and SeaBIOS falls back to CMOS.

In RTL fw_cfg is a selector register and a blob with an index, and its
contents can be generated at build time. A CMOS/RTC is battery-backed
state, BCD time and an alarm, mostly answering questions the platform
already knows. Adding a configuration item is a table entry rather than
a new register in a fixed 128-byte layout.

The CMOS device stays for time and the shutdown status byte.

- [ ] **fw_cfg is a good first peripheral to move to RTL.** It is the
      cheapest device in the machine and it has a frozen software
      reference to diff against. Moving it is an edit to
      `cosim_port_is_rtl()` plus a Wishbone slave.
- [ ] Decide what else it should carry beyond `etc/e820` — boot order,
      device presence, board revision. Currently only what SeaBIOS needs
      to size memory.

## Direction: CMOS as a compatibility surface, populated at reset-exit

fw_cfg (above) is the platform-to-firmware channel. **CMOS is a
different thing and both are needed**: guest operating systems read CMOS
directly and will never speak fw_cfg. tiny386's own `ide_fill_cmos()`
exists for exactly this — its comment says it fixes "MS-DOS
compatibility mode" in Win9x. SeaBIOS itself never reads those bytes
(`CMOS_DISK_DATA` is defined in `src/hw/rtc.h` and used nowhere).

### What the RTL block is

Measured by driving `0x70`/`0x71` with a computed pattern across all 128
registers: **119 of 128 are pure storage.** So the block is an index
register, a 128x8 SRAM, and a small BCD RTC. Only nine registers carry
behaviour:

| register | behaviour |
|---|---|
| `00,02,04,06,07,08,09` | BCD seconds/minutes/hours/weekday/day/month/year |
| `32` | BCD century — sits *inside* the NVRAM range, so the decode is not a clean split |
| `0A` | UIP read-only; divider and rate-select writable |

Plus `0B` control, `0C` interrupt flags (read-to-clear), `0D` valid-RAM,
and the IRQ8 periodic interrupt driven by `0A`'s rate select.

Storage is ~1 Kbit. One EBR is gross overkill; distributed RAM is the
sensible choice. Either is noise against 208 EBR / 83,640 LUT4.

### Persistence: an ESP32 on the board, not a coin cell

The motherboard layer carries an **ESP32 / WiFi module** as the board
controller. It obtains current time over **NTP**, so the RTC does not
need battery-backed timekeeping.

**Settled:** CMOS writes propagate to the controller, which decides what
persists. No battery-backed state on the FPGA side. The write-back path
is a software matter on the controller, is not on any critical path, and
is deliberately not modelled — it changes nothing about the machine the
guest sees.

Consequence for the model, and it is not cosmetic: the RTC is **seeded
once at reset from an external source and then free-runs**, rather than
continuously reflecting a host clock. A seeded RTC also makes
simulation runs **deterministic**, which the free-running host-time
version is not.

### One control channel: controller -> chipset -> fw_cfg -> SeaBIOS

The board controller feeds configuration to the chipset, which serves it
to the firmware over fw_cfg and materialises the guest's view in CMOS.

**This makes fw_cfg a RAM the chipset writes, not a build-time ROM** —
so boot order, drive geometry, advertised memory and board revision all
change *without re-synthesising a bitstream*. The store and its contents
are separate concerns: `fw_cfg.c` is the store, `platform_cfg.c` decides
what goes in it.

A useful consequence already visible in the model: advertised RAM need
not equal fitted RAM.

### Population: a chipset reset-exit initialisation vector

At reset de-assertion the chipset reads a configuration image and
populates the CMOS SRAM before the CPU begins executing.

- **Transport is TBD (SPI or I2C)** and nothing here assumes one. What
  is fixed is *when* (reset-exit, before first fetch) and *what* (a
  CMOS image plus an RTC seed) — not how it arrives.
- On ECP5 the fallback costs nothing: block RAM initial contents are
  part of the bitstream, so a default image can be preloaded with no
  logic at all.

Drive geometry is **not** an exception to this, though it looked like
one at first — see the block storage section below.

- [ ] **CMOS SRAM is the second RTL peripheral candidate**, after
      fw_cfg. Both then have a frozen software reference to diff
      against.
- [ ] Settle the config transport (SPI vs I2C) when the board
      controller interface is defined.

## Direction: block storage backed by the ESP32

The board controller services the block-storage back end, as it does the
network. The guest-visible device stays a period-correct IDE/ATA
controller; what sits behind it is the controller's problem, and the
mechanics of that are software to be solved later.

**No spinning disks are supported.** That is a product decision (see
"Who this is for") and it removes the 40-pin header, the cable and the
drive bay along with the drive.

**This settles the drive-geometry question completely, and the reasoning
has moved twice — so the final position is worth stating plainly.**

The original concern was that geometry cannot come from a static image
because it is unknown until the drive answers IDENTIFY. That assumed a
*physical* drive being probed. With no physical drives at all, there is
nothing to discover: **the controller decides what IDENTIFY reports.**
Geometry is not derived, it is declared. There is no discovery step to
lose.

The only remaining question is which channel carries it, and dropping
PCI answered that (below): the legacy CMOS bytes, not a `bios-geometry`
fw_cfg file. Both of these travel the same path as everything else:

- `bios-geometry` as an fw_cfg file, which SeaBIOS already reads —
  `CONFIG_HOST_BIOS_GEOMETRY=y` is set in the fork's config, and
  `boot_lchs_find_ata_device()` looks devices up by a path such as
  `/pci@i0cf8/ide@1,1/drive@0/disk@0`. That matches where
  `piix3_ide_init(pcibus, piix3_devfn + 1)` puts the controller.
- the legacy CMOS type-47 bytes in the reset image, for guests that read
  them directly rather than going through the BIOS.

Nothing has to wait for IDENTIFY, and no SeaBIOS patch is needed.

Open:

- [ ] **Vendor `ide.[ch]` and `piix3_ide_init`**, add the port ranges
      (`0x1f0-0x1f7`/`0x3f6`, `0x170-0x177`/`0x376`) and the 16- and
      32-bit data paths back to the dispatch.
- [ ] Add `bootorder` and `bios-geometry` to the reset-exit image. Both
      are small text blobs; note the current 512-byte per-item cap.
- [ ] Decide whether to carry `ide_fill_cmos()`. SeaBIOS never reads
      those bytes (`CMOS_DISK_DATA` is defined in `src/hw/rtc.h` and used
      nowhere); the fork's comment attributes them to Win9x "MS-DOS
      compatibility mode". Out of scope for DOS, in scope if Windows
      ever is.
- [ ] A disk image for simulation. This is the last thing standing
      between the co-simulation and an actual DOS boot.

### Storage back end: the physical stores — OPEN, parked

**Not being solved now.** The shape below is settled enough to build on;
the remaining choices are lower priority than the socket question above
and are pinned here rather than pursued:

- NOR vs NAND, and the exact capacity
- read-only vs read-write regions, and where the boundary sits
- whether the ESP32 becomes FPGA configuration master
- copy-on-write overlay (NOR base, SD overlay) or a simpler split
- image format: `.iso` versus BIN/CUE, which is also the CD-audio decision
- caching policy between tiers 2 and 3, which is what keeps the
  synchronous ATA path inside its timeouts
- in-band image selection via an `emulink`-style channel, or web UI only

Two physical stores are expected, plus the network. Formats and
read/write policy are undecided; what follows is the shape and the
things worth settling early.

| tier | medium | capacity | role | latency |
|---|---|---|---|---|
| 1 | NOR (or NAND) | ~56 MiB usable | firmware, config, shipped DOS system, recovery — **read-only** | us, fastest in the machine |
| 2 | SD card | GB | **optical images**, writable overlay, cache for tier 3 | ~1 ms |
| 3 | network (SMB) | unbounded | the image library | ~100 ms |

**Tier 2 is not optional, and CD images are why.** A single disc image
is 650-700 MB as `.iso`, and nearer 750 MB as BIN/CUE once Red Book
audio tracks are included — which the CD-audio decision above argues
for. Tier 1 cannot hold even one, at any NOR size that is sensible to
fit. The tiers are complementary rather than alternatives:

- tier 1 is small, immutable and fast — the system
- tier 2 is large and writable — the content
- tier 3 is unbounded and slow — the library

#### Tier 1 may need no new part

**Both controllers already require NOR flash for their own reasons.** An
ESP32 module has integrated flash, and the ECP5 must load its bitstream
from SPI NOR at configuration time — that part is not optional. A
bitstream leaves useful room in a typical 16 Mbit/16 MByte device.

So the question is not "which flash do we add" but "can the flash that
has to exist anyway also carry the BIOS images, the reset-exit
configuration and a recovery set". That is the BOM-reducing answer and
it is consistent with everything else here.

- [ ] **Consider making the ESP32 the FPGA configuration master.** If
      the ESP32 owns the SPI flash and configures the ECP5 rather than
      letting it self-load, then: one flash, no bus arbitration between
      two masters, bitstreams updatable over WiFi, and a recovery
      bitstream becomes possible. It also fits the controller already
      being "the brains". The alternative — sharing one flash between
      ECP5 and ESP32 — needs a mux or arbitration and buys nothing.
- [ ] **RO vs RW is really two questions.** Recovery and golden images
      want to be read-only, because that is what makes the fallback
      trustworthy; configuration wants to be writable. Splitting by
      region rather than by device answers both.
- [ ] NOR vs NAND: NOR is the obvious fit at this size — byte
      addressable, no ECC, no bad-block management, no FTL. NAND only
      earns its complexity at capacities the SD card already covers.
      **The ECP5 configures from SPI NOR and cannot boot from raw NAND**,
      so a NAND choice means a second device regardless.

#### The real question: is the config ROM also bulk storage?

Measured on the actual part — LFE5U-85F, `ecppack`:

| | size |
|---|---|
| bitstream, measured uncompressed | **1,927,725 bytes (1.84 MiB)** |
| **budget: single boot** | **4 MiB** |
| **budget: dual boot** | **8 MiB** |
| left over on a 16 MiB NOR (dual boot) | 8 MiB |
| left over on a 32 MiB NOR (dual boot) | 24 MiB |
| left over on a 64 MiB NOR (dual boot) | 56 MiB |

The measurement sits comfortably inside the budget — 1.84 MiB against a
4 MiB ceiling leaves room for growth without revisiting the part.

(A trivial design compresses to 0.27 MiB, but that is mostly zeros and
not representative. A real design lands nearer 1.2-1.5 MiB compressed.)

**The stated danger is real but is a consequence of one choice, not of
bulk storage itself.** Corruption requiring a JTAG programmer only
follows if the *FPGA self-configures from the shared flash*. Two
mitigations, and the first removes the risk rather than reducing it:

- **ESP32 as configuration master.** If the controller pushes the
  bitstream into the ECP5 over SPI rather than the FPGA loading itself,
  a corrupted bitstream region is recoverable *over WiFi* — the ESP32
  refetches and rewrites it. JTAG stops being the recovery path. The
  ESP32's own firmware lives in its module's integrated flash, which is
  a separate device and never used for bulk.
- **Hardware write protection on the bitstream sectors.** NOR block
  protection and the `WP#` pin can make the bitstream region physically
  unwritable while the bulk region stays writable. Cheap, and it means
  bulk activity *cannot* corrupt configuration.

**Dual boot is itself most of the answer**, and the budget above already
reserves for it. ECP5 multiboot falls back to a golden image when the
primary fails its CRC — so a corrupted primary self-recovers, and the
ESP32 can then rewrite it. That holds *even if the FPGA self-configures*,
provided the golden image sits in write-protected sectors. Combined with
the `WP#` protection above, JTAG stops being the recovery path in every
case except physical damage to the device.

**What the config ROM should and should not carry:**

- **Should**, and this eliminates a part: bitstream and golden copy,
  BIOS and VGA BIOS images, the reset-exit configuration image, and a
  **read-only rescue system**. That last one completes the fallback
  story already decided for the soft-core — with it, the machine boots
  to something with no SD card and no network at all.
- **Should not** be the read-write C: drive. Two reasons: NOR costs
  orders of magnitude more per byte than SD, and **NOR erase latency
  (tens to hundreds of ms per sector) interacts badly with the
  synchronous ATA interface** — the same BSY-polling timeout hazard as
  the network path, but on the write side and unavoidable.

So it **eliminates a dedicated storage flash, not the SD card.**
Read-only bulk on NOR is excellent; read-write bulk on NOR is the wrong
medium.

#### 64 MiB NOR is readily available, and 56 MiB changes the role

With dual boot reserved, a 64 MiB part leaves **56 MiB** — which is not
"a rescue image" territory, it is *a shipped system* territory. A
minimal DOS with drivers and utilities is ~10-20 MB; a period 486 often
shipped with a 40-540 MB drive.

That buys a real product property: **the machine boots to a working DOS
with no SD card fitted and no network reachable.** Out of the box, and
after any failure of the other two tiers. It also completes the fallback
story end to end — soft-core serves defaults, NOR serves a bootable
system.

**And NOR is the *fastest* store in the machine, not the slowest.**
Quad-SPI NOR reads run at tens of MB/s; SD in SPI mode is a few MB/s,
and a period IDE drive managed 2-5 MB/s. The read-only tier is quicker
than everything above it — an inversion worth exploiting rather than
apologising for. Only erase and program are slow, which is exactly why
it stays read-only.

- [ ] **Consider a copy-on-write overlay: NOR base, SD overlay.** The
      guest sees one writable `C:`; reads fall through to NOR, writes
      land on SD. That gives a writable feel over an immutable base, and
      an SD failure loses only the changes rather than the system.
      Resetting to a known-good machine becomes "discard the overlay".

#### Tier 2: SD is slower than it needs to be, which is fine

Worth calibrating: **a period 486-era IDE drive managed roughly 2-5
MB/s.** Even SD in SPI mode outruns that, and the ESP32's 4-bit SDMMC
mode considerably so. The guest cannot tell the difference, and DOS
workloads are light.

**Reliability is the real concern, not speed.** Consumer cards have
opaque wear levelling and corrupt on sudden power loss. Mitigations are
architectural rather than heroic: keep golden images on tier 1, treat
the card as replaceable bulk media, and consider write-back caching with
an explicit flush.

#### Tier 2 as cache is what makes tier 3 safe

This closes the ATA-timeout risk flagged above. ATA is synchronous — the
guest polls BSY — and a ~100 ms network read is long enough to trip BIOS
and driver timeouts. **Caching network images onto the SD card turns a
100 ms path into a ~1 ms one**, and makes the network a library rather
than a live block device. That is a strong argument for the tiering
independent of capacity.
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

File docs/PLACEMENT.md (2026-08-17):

# Pseudo-schematic and general placement

**General placement only.** Orientation and exact geometry are not fixed
here; what is fixed is which block connects to which FPGA edge, because
that is what determines routing difficulty and it is derivable now from
data rather than discovered during layout.

Derived from `Data/pinmap_*.csv` — see [BOARD.md](BOARD.md) for the
gates this feeds.

---
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

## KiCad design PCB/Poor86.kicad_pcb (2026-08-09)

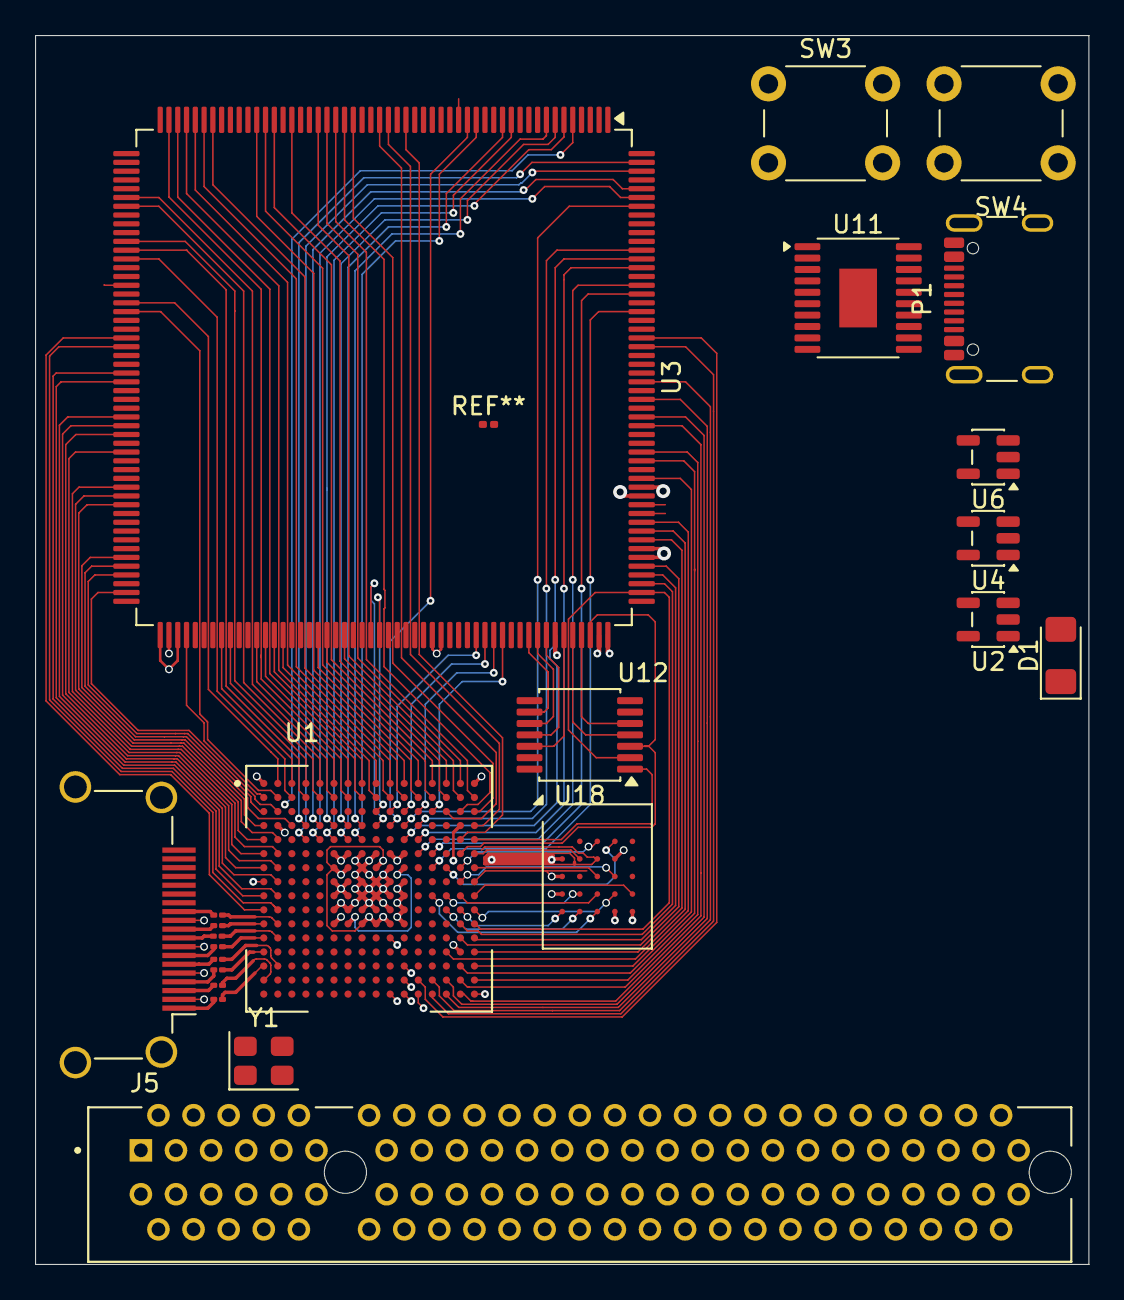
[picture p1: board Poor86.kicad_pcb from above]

Board: 4 copper layers, 60.0 x 70.0 mm, 24 parts (1 on the bottom side), 143 nets.

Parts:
C35, C36, C45, C46, C47, C48, C49, C50: 2.2nF; C_01005_0402Metric
D1: 1N4001; D_1206_3216Metric_Pad1.42x1.75mm_HandSolder
J5: 10018783-10202TLF; AMPHENOL_10018783-10202TLF
J6: HDMI_A; HDMI_A_Amphenol_10029449-x01xLF_Horizontal
P1: USB_C_Plug_USB2.0; USB_C_Receptacle_GCT_USB4105-xx-A_16P_TopMnt_Horizontal
SW3, SW4: SW_Push_Dual; SW_PUSH_6mm
U1: LFE5U-25F-6BG256C; BGA256C80P16X16_1400X1400X170
U2, U4, U6: TLV62569DBV; SOT-23-5
U3: AM5x86 PQFP208; LQFP-208_28x28mm_P0.5mm
U5: ESP-12F; ESP-12E
U11: CH552T; TSSOP-20-1EP_4.4x6.5mm_P0.65mm_EP2.15x3.35mm
U12: IS66WVH8M8BLL-100B1LI; BGA-24_6x8mm_Layout5x5_P1.0mm
U18: 4068; TSSOP-14_4.4x5mm_P0.65mm
Y1: CMOS-50MHz; Oscillator_SMD_Abracon_ASE-4Pin_3.2x2.5mm

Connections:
+1V1: U1.G6 (VCC), U1.G7 (VCC), U1.G9 (VCC), U1.L8 (VCC), U1.L9 (VCC), U1.L10 (VCC)
+2V5: U1.G11 (VCCAUX), U1.L7 (VCCAUX)
+3V3: D1.2 (A), U1.F6 (VCCIO0), U1.F7 (VCCIO0), U1.F10 (VCCIO1), U1.F11 (VCCIO1), U1.H6 (VCCIO7), U1.H7 (VCCIO7), U1.H11 (VCCIO2), U1.J6 (VCCIO6), U1.J7 (VCCIO6), U1.J11 (VCCIO2), U1.K11 (VCCIO3), U1.L6 (VCCIO8), U1.L11 (VCCIO3), U3.2 (VCC), U3.9 (VCC), U3.14 (VCC), U3.19 (VCC), U3.20 (VCC), U3.22 (VCC), U3.23 (VCC), U3.25 (VCC), U3.29 (VCC), U3.35 (VCC), U3.38 (VCC), U3.42 (VCC), U3.44 (VCC), U3.45 (VCC), U3.54 (VCC), U3.56 (VCC), U3.60 (VCC), U3.62 (VCC), U3.69 (VCC), U3.77 (VCC), U3.80 (VCC), U3.82 (VCC), U3.86 (VCC), U3.89 (VCC), U3.95 (VCC), U3.98 (VCC), U3.102 (VCC), U3.106 (VCC), U3.111 (VCC), U3.114 (VCC), U3.121 (VCC), U3.128 (VCC), U3.131 (VCC), U3.133 (VCC), U3.134 (VCC), U3.136 (VCC), U3.137 (VCC), U3.139 (VCC), U3.150 (VCC), U3.155 (VCC), U3.162 (VCC), U3.163 (VCC), U3.169 (VCC), U3.172 (VCC), U3.176 (VCC), U3.179 (VCC), U3.183 (VCC), U3.185 (VCC), U3.188 (VCC), U3.191 (VCC), U3.198 (VCC), U3.200 (VCC), U3.205 (VCC), U12.B4 (VCC), U12.D1 (VCCQ), U12.E4 (VCCQ__1), U18.14 (Vdd), Y1.1 (EN), Y1.4 (Vdd)
+5V: U2.1 (EN), U2.4 (VIN), U4.1 (EN), U4.4 (VIN), U6.1 (EN), U6.4 (VIN)
/FPGA/DQ0: U1.J15 (PR23B), U12.D3 (DQ0)
/FPGA/DQ1: U1.J14 (PR20C), U12.D2 (DQ1)
/FPGA/DQ2: U1.H15 (PR20B), U12.C4 (DQ2)
/FPGA/DQ3: U1.K16 (PR23C), U12.D4 (DQ3)
/FPGA/DQ4: U1.J16 (PR23A), U12.D5 (DQ4)
/FPGA/DQ5: U1.J13 (PR17C), U12.E3 (DQ5)
/FPGA/DQ6: U1.K14 (PR20D), U12.E2 (DQ6)
/FPGA/DQ7: U1.K15 (PR23D), U12.E1 (DQ7)
/FPGA/OB_CLKt: U1.F16 (PR14A), U12.B2 (CK)
/FPGA/OB_RWDS: U1.G16 (PR20A), U12.C3 (RWDS)
/FPGA/~CS: U1.G15 (PR14B), U1.N8 (PB15A), U12.A3 (~CS)
/FPGA/~RESET: U1.G14 (PR14C), U12.A4 (~RESET)
/eternal_perif/CK+: C49.1, U1.L1 (PL26A)
/eternal_perif/CK-: C50.1, U1.L2 (PL26B)
/eternal_perif/D0+: C47.1, U1.M1 (PL26C)
/eternal_perif/D0-: C48.1, U1.M2 (PL26D)
/eternal_perif/D1+: C45.1, U1.N1 (PL32A)
/eternal_perif/D1-: C46.1, U1.P2 (PL32B)
/eternal_perif/D2+: C35.1, U1.P1 (PL35A)
/eternal_perif/D2-: C36.1, U1.R1 (PL35B)
A2: U1.D11 (PT51A), U3.202 (A2)
A3: U1.D12 (PT58A), U3.197 (A3)
A4: U1.E11 (PT51B), U3.196 (A4)
A5: U1.E12 (PT58B), U3.195 (A5)
A6: U1.F12 (PR8D), U3.193 (A6)
A7: U1.F13 (PR8C), U3.192 (A7)
A8: U1.G13 (PR11B), U3.190 (A8)
A9: U1.R12 (PR44A), U3.187 (A9)
A10: U1.T13 (PR44B), U3.186 (A10)
A11: U1.R13 (PR41C), U3.182 (A11)
A12: U1.T14 (PR41D), U3.180 (A12)
A13: U1.R14 (PR41B), U3.178 (A13)
A14: U1.T15 (PR38D), U3.177 (A14)
A15: U1.R15 (PR38C), U3.174 (A15)
A16: U1.R16 (PR35B), U3.173 (A16)
A17: U1.P15 (PR32B), U3.171 (A17)
A18: U1.P16 (PR35A), U3.166 (A18)
A19: U1.N14 (PR35D), U3.165 (A19)
A20: U1.N16 (PR32A), U3.164 (A20)
A21: U1.M15 (PR26D), U3.161 (A21)
A22: U1.M16 (PR26C), U3.160 (A22)
A23: U1.L15 (PR26B), U3.159 (A23)
A24: U1.L16 (PR26A), U3.158 (A24), U18.2 (A)
A25: U1.F15 (PR11C), U3.154 (A25), U18.3 (B)
A26: U3.153 (A26), U18.5 (D)
A27: U3.152 (A27), U18.4 (C)
A28: U3.151 (A28), U18.12 (H)
A29: U3.149 (A29), U18.11 (G)
A30: U3.148 (A30), U18.10 (F)
A31: U3.147 (A31), U18.9 (E)
AHOLD: U1.D10 (PT47A), U3.17 (AHOLD)
BREQ: U1.C16 (PR5A), U3.30 (BREQ)
CLK: U1.E15 (PR8B), U3.24 (CLK)
D0: U1.C13 (PT60B), U3.144 (D0)
D1: U1.C12 (PT56B), U3.143 (D1)
D2: U1.C11 (PT49B), U3.142 (D2)
D3: U1.C10 (PT44B), U3.141 (D3)
D5: U1.C9 (PT38B), U3.130 (D5)
D6: U1.D9 (PT40A), U3.129 (D6)
D7: U1.A14 (PT65B), U3.126 (D7)
D8: U1.B13 (PT60A), U3.124 (D8)
D9: U1.B12 (PT56A), U3.123 (D9)
D10: U1.A9 (PT42A), U3.119 (D10)
D11: U1.A8 (PT29B), U3.118 (D11)
D12: U1.A7 (PT29A), U3.117 (D12)
D13: U1.A6 (PT18B), U3.116 (D13)
D14: U1.A4 (PT6B), U3.113 (D14)
D15: U1.A3 (PT6A), U3.112 (D15)
D16: U1.B1 (PL2A), U3.108 (D16)
D17: U1.C2 (PL5B), U3.103 (D17)
D18: U1.C1 (PL5A), U3.101 (D18)
D19: U1.D3 (PL2D), U3.100 (D19)
D20: U1.D1 (PL8A), U3.99 (D20)
D21: U1.E2 (PL8B), U3.93 (D21)
D22: U1.E1 (PL11D), U3.92 (D22)
D23: U1.F2 (PL11C), U3.91 (D23)
D24: U1.F1 (PL14A), U3.87 (D24)
D25: U1.G2 (PL14B), U3.85 (D25)
D26: U1.G1 (PL20A), U3.84 (D26)
D27: U1.H2 (PL20B), U3.83 (D27)
D28: U1.J2 (PL23B), U3.79 (D28)
D29: U1.J1 (PL23A), U3.78 (D29)
D30: U1.K2 (PL23D), U3.75 (D30)
D31: U1.K1 (PL23C), U3.74 (D31)
D~C: U1.A13 (PT65A), U3.39 (D~C)
GNDD: J6.2 (D2S), J6.5 (D1S), J6.8 (D0S), J6.11 (CKS), J6.17 (GND), J6.SH, U1.A1 (GND1), U1.A16 (GND1), U1.D2 (GND1), U1.D15 (GND1), U1.F8 (GND1), U1.F9 (GND1), U1.G8 (GND1), U1.G10 (GND1), U1.H1 (GND1), U1.H8 (GND1), U1.H9 (GND1), U1.H10 (GND1), U1.H16 (GND2), U1.J8 (GND2), U1.J9 (GND2), U1.J10 (GND2), U1.K6 (GND2), U1.K7 (GND2), U1.K8 (GND2), U1.K9 (GND2), U1.K10 (GND2), U1.N2 (GND2), U1.N15 (GND2), U1.T1 (GND2), U1.T5 (GND2), U1.T12 (GND2), U1.T16 (GND2), U2.2 (GND), U3.1 (GND), U3.10 (GND), U3.15 (GND), U3.21 (GND), U3.28 (GND), U3.36 (GND), U3.43 (GND), U3.52 (GND), U3.53 (GND), U3.55 (GND), U3.57 (GND), U3.61 (GND), U3.76 (GND), U3.81 (GND), U3.88 (GND), U3.94 (GND), U3.97 (GND), U3.104 (GND), U3.105 (GND), U3.107 (GND), U3.110 (GND), U3.115 (GND), U3.120 (GND), U3.122 (GND), U3.132 (GND), U3.135 (GND), U3.138 (GND), U3.146 (GND), U3.156 (GND), U3.157 (GND), U3.170 (GND), U3.175 (GND), U3.181 (GND), U3.184 (GND), U3.189 (GND), U3.199 (GND), U3.201 (GND), U3.208 (GND), U4.2 (GND), U6.2 (GND), U11.18 (GND), U12.B1 (~CK), U12.B3 (VSS), U12.C1 (VSSQ), U12.E5 (VSSQ__1), U18.7 (Vss), Y1.2 (GND)
HOLD: U1.E8 (PT33A), U3.16 (HOLD)
HOLDA: U1.D16 (PR8A), U3.26 (HOLDA)
INTR: U1.B8 (PT35B), U3.50 (INTR)
INV: U1.B2 (PL2B), U3.71 (INV)
LRC_GPLL0T_IN: U1.P11 (PR47C), Y1.3 (OUT)
M~IO: U1.B14 (PT67A), U3.37 (M~IO)
NMI: U1.B7 (PT27B), U3.51 (NMI)
unnamed: D1.1 (K), SW3.2, SW4.2, U11.20 (3V3)
unnamed: C49.2, J6.10 (CK+)
unnamed: C50.2, J6.12 (CK-)
unnamed: C47.2, J6.7 (D0+)
unnamed: C48.2, J6.9 (D0-)
unnamed: C45.2, J6.4 (D1+)
unnamed: C46.2, J6.6 (D1-)
unnamed: C35.2, J6.1 (D2+)
unnamed: C36.2, J6.3 (D2-)
unnamed: P1.A6 (D+), U11.14 (P36)
unnamed: P1.A7 (D-), U11.15 (P37)
unnamed: P1.A1 (GND), P1.A12 (GND), P1.B1 (GND), P1.B12 (GND)
unnamed: U1.M10 (TDO), U3.168 (TDI)
unnamed: SW3.1, U11.6 (RST)
unnamed: P1.A4 (VBUS), P1.A9 (VBUS), P1.B4 (VBUS), P1.B9 (VBUS), U11.19 (VBUS)
PCD: U1.A11 (PT53A), U3.41 (PCD)
PWT: U1.A12 (PT53B), U3.40 (PWT)
RESET: U1.B10 (PT44A), U3.48 (RESET)
SRESET: U1.B6 (PT22B), U3.58 (SRESET)
TCK: U1.T10 (TCK), U3.18 (TCK), U11.5 (P17)
TDI: U1.R11 (TDI), U11.3 (P15)
TDO: U3.68 (TDO), U11.4 (P16)
TMS: U1.T11 (TMS), U3.167 (TMS), U11.2 (P14)
UADDR: U1.E16 (PR11D), U18.1 (K)
WB~WT: U1.B4 (PT11B), U3.64 (WB~WT)
W~R: U1.C14 (PR2C), U3.27 (W~R)
~A20M: U1.A10 (PT42B), U3.47 (~A20M)
~ADS: U1.E5 (PT13A), U3.203 (~ADS)
~BE0: U1.C15 (PR5B), U3.31 (~BE0)
~BE1: U1.B16 (PR2A), U3.32 (~BE1)
~BE2: U1.A15 (PT67B), U3.33 (~BE2)
~BE3: U1.B15 (PR2B), U3.34 (~BE3)
~BLAST: U1.D5 (PT13B), U3.204 (~BLAST)
~BOFF: U1.D6 (PT20B), U3.6 (~BOFF)
~BS8: U1.D8 (PT33B), U3.8 (~BS8)
~BS16: U1.D7 (PT24B), U3.7 (~BS16)
~CACHE: U1.A2 (PT4A), U3.70 (~CACHE)
~EADS: U1.B11 (PT49A), U3.46 (~EADS)
~FLUSH: U1.B9 (PT38A), U3.49 (~FLUSH)
~HITM: U1.B5 (PT15B), U3.63 (~HITM)
~KEN: U1.E7 (PT24A), U3.13 (~KEN)
~LOCK: U1.D4 (PT9B), U3.207 (~LOCK)
~PLOCK: U1.E4 (PT9A), U3.206 (~PLOCK)
~RDY: U1.E6 (PT20A), U3.12 (~RDY)
~SMIACT: U1.A5 (PT18A), U3.59 (~SMIACT)
~SMI: U1.B3 (PT4B), U3.65 (~SMI)

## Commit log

2026-07-26 broken 386 symbol
    [Poor86.kicad_pcb, am5x86.kicad_sch, sch.kicad_sch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]
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2026-08-14 Record the modern-memory goal and why it makes the cache central
    Adds a design goal to the memory subsystem section: the main store
    should be a modern part -- synchronous rather than the period's
    asynchronous FPM/EDO DRAM, and burstable. What "modern" means precisely
    is still undefined, and this records the goal and the tension rather
    than a decision.
    The tension is the substance. Modern memory is bandwidth-oriented and a
    386 or 486 is latency-bound, so they want opposite things. A 386SX has
    no burst at all and a 486 bursts only for four-transfer line fills,
    which means the CPU issues exactly the pattern modern memory is worst
    at: small, frequently random, one at a time.
    Names the trap: bu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
2026-08-14 Note the SX decision doubles memory-subsystem work; four-word ceiling
    Two additions to the memory subsystem section, and a cross-reference
    from the CPU cost list.
    First: a 486 burst is four transfers, sixteen bytes, and that is the
    entire amortisation window in this machine -- the SX has no burst at
    all. A part with a long fixed setup cost cannot amortise it across four
    words, so the usual instinct of picking for sustained bandwidth is
    backwards. Low latency beats high bandwidth here and it is not close.
    That favours parallel SRAM or PSRAM and disfavours HyperRAM, whose pin
    efficiency is attractive but whose initial latency wants long bursts
    this machine will never issue. Capacity is not th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
2026-08-14 Add the measured resource budget a cache has to work with
    Rolls in the distributed-RAM finding from ao486-cpu-oss, which is the
    one hard resource figure the cache design has so far and came from a
    measurement already paid for.
    An LFE5U-85F has two separate memory pools and a cache wants both: 208
    EBR for data arrays, where density matters, and 10,455 RAM LUTs for tag
    stores and small buffers, where async or single-cycle read matters.
    Sizing against the wrong pool is an easy mistake, since tags need to
    resolve a hit without adding a pipeline stage.
    ao486 consumes 260 RAM LUTs (2%) and 12 EBR, so roughly 10,195 RAM LUTs
    and nearly all block RAM remain -- and on the hard-CPU path, where no
    x8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
2026-08-15 Plan of record: rename, relabel, cache canon, and the board document
    DECISIONS.md becomes PLAN_OF_RECORD.md. The old name oversold it --
    almost nothing here is decided, and the new name is meant literally:
    the currently-agreed plan, expected to change. Adds a status section
    saying plainly that no hardware exists, nothing is irreversible, and
    several conclusions reversed within the conversation that produced them.
    Headings now say what they are rather than all claiming "Decided":
    Requirement (given, not derived), Eliminated (ruled out with a reason
    meant to outlive the moment), Direction (current preference, not
    settled), Design goal, OPEN. Ruling things out is recorded as forward
    progress a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
2026-08-15 Pin maps as CSV, and fix two broken KiCad symbols
    Data/ gains machine-readable pin maps for every part evaluated so far,
    extracted from the datasheets rather than transcribed by hand:
    pinmap_am5x86_sqfp208.csv 208 pins
    pinmap_intel386sx_pqfp100.csv 100 pins
    pinmap_ti486sxlc_pqfp100.csv 100 pins
    pinmap_ecp5_lfe5u85f_cabga381.csv 205 usable I/O balls
    pinmap_386sx_vs_ti486sxlc_ties.csv the 8 pins needing a 0R option
    Note the Am5x86 package is SQFP (Shrink Quad Flat Pack) in AMD's own
    wording, not PQFP -- worth using their term when sourcing parts and
    footprints.
    Symbol fixes:
    - am5x86.kicad_sym had pin 26 named HOLDA; the datasheet says HLDA.
    Every othe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
    [pinmap_386sx_vs_ti486sxlc_ties.csv, pinmap_am5x86_sqfp208.csv, pinmap_ecp5_lfe5u85f_cabga381.csv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]
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2026-08-15 Add placement pseudo-schematic; answers gate G3
    docs/PLACEMENT.md records the pin budget and FPGA edge allocation, both
    derived from the datasheet CSVs rather than estimated, plus a relative
    board floorplan.
    Two results that change earlier assumptions.
    The CPU bus is 97 pins, not the ~76 used until now -- that figure was for
    a 386SX-class bus. The Am5x86 essential set is 30 address, 32 data and 35
    control. Against 205 available PIO the full budget comes to 190, leaving
    15 spare, so it fits but not comfortably. And the FULL Am5x86 signal set
    does not fit: adding parity, JTAG and the deferrable control group totals
    206, one over. Something must be dropped, and the cheap candidates are
    parity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
2026-08-15 Reserve ECP5 bank 8 for configuration and DFx only
    Bank 8 of the CABGA381 is the interface the FPGA boots through -- all 13
    balls carry configuration functions. Anything else assigned there either
    collides with configuration or silently constrains it, and the failure
    would surface at bring-up on a board that cannot be reprogrammed to fix
    it.
    Permitted without a waiver: the SPI NOR configuration flash, the QSPI
    PSRAM sharing that bus by design, and DFx -- JTAG, test points, bring-up
    and debug access. Anything else requires a waiver recorded in the plan of
    record naming the signal and stating why no other bank will serve.
    Recorded in three places so it cannot be missed: as a reserved-resourc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
2026-08-15 Correct the HDMI signalling constraint
    Fake TMDS does not require true LVDS -- the restriction is on
    differential pairs. So the constraint is not which banks support LVDS
    output, but whether adjacent A/B PIO pair sites are available, since the
    two halves of each pair must be matched or skew destroys the signal at
    these rates.
    That makes the analysis concrete rather than hedged. HDMI needs 4 pairs
    and every usable edge has ample: PT 29, PR 17, PL 16. So HDMI placement
    is free among PT/PL/PR and should be chosen by proximity to the
    connector. PB is excluded because bank 8 is reserved for configuration
    and DFx, not because of its pair count.
    Replaces two errors made in drafting: first asserti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
2026-08-15 Decide: all ECP5 VCCIO rails are 3.3 V
    One I/O voltage across the device. This removes a class of constraint
    rather than settling a single question -- banks sharing a VCCIO rail
    must share a voltage, so a mixed-voltage design forces signal groups
    into particular banks and can strand I/O that is electrically fine but
    at the wrong potential. With a single rail, signal groups are assigned
    to banks by geometry alone.
    It follows from decisions already made: the CPU is a 3.3 V part chosen so
    its bus reaches the FPGA without level shifters, and fake-TMDS video
    drives ordinary 3.3 V I/O. The only 5 V in the design is on the mezzanine,
    behind translating transceivers, so it never reaches an FPGA ban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
2026-08-15 Fold the schematic annotations into the board and placement docs
    The schematic carries more decisions than the parts list showed.
    Power: annotations give the feedback maths against the TLV62569's 0.6 V
    reference -- 15k/18k for 1.10 V, 15k/4.7k for 2.51 V, and 15k or 16k over
    3.3k for 3.33 V or 3.51 V. So JP6 swaps the upper divider leg between 15k
    and 16k; it is a solder jumper on the feedback network, set at build and
    changeable with an iron.
    Pin saver: both the FPGA and Am5x86 sheets are annotated "pin saver
    option. Reduces address space to 16 MB". Dropping A24-A31 takes the CPU
    bus from 97 pins to 89 and the total budget from 190 to 182 of 205, so
    23 spare rather than 15. It is cheaper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
2026-08-15 Add an SVG placement illustration
    docs/placement.svg renders the floorplan from PLACEMENT.md: the FPGA
    with its four edges and ball counts, what connects to each, pin counts
    annotated on every bus, and the running budget.
    It carries the constraints that are actually load-bearing, so the picture
    and the text cannot drift apart: the CPU bus spanning PT and PR because
    no single edge holds it, memory on PL, bank 8 marked config and DFx only,
    HDMI as four differential pairs from PT slack, and the mezzanine shown
    buffered behind transceivers with the daughterboard off the critical
    path.
    Linked from PLACEMENT.md above the ASCII version, which is kept because
    it diffs and the SVG does not.
    Co-Aut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
2026-08-15 Correct: bus transceivers live on the mezzanine, not the baseboard
    The connector carries the raw 486 bus plus four lines to drive the
    transceivers; buffering and level translation happen on the
    daughterboard. Three consequences, and the second is the useful one:
    - The baseboard carries no transceiver BOM or area -- roughly seven
    packages that would otherwise sit beside the connector.
    - The baseboard stays a single 3.3 V domain. Translation is the
    mezzanine's business, so each daughterboard chooses its own voltage --
    5 V for a period part, 3.3 V for something modern -- without the
    baseboard committing to either. That is more flexible than translating
    centrally, and it is why the ea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
2026-08-15 HARD SPEC: the mezzanine interface is 3.3 V and not 5 V tolerant
    A protection requirement, not a preference -- a daughterboard driving 5 V
    into the connector damages the baseboard. Recorded as a hard spec, to
    appear on the connector pinout, in any mezzanine template, and
    silkscreened at the connector.
    There is no requirement for 5 V at the mezzanine and none is provided for
    signalling. This does not exclude 5 V period parts, including period
    Cirrus devices -- it relocates the responsibility. A daughterboard
    carrying a 5 V part translates on the daughterboard, next to the part,
    where the designer of that board can see the requirement. The baseboard
    never takes a position on anyone else's vol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
2026-08-15 File the mezzanine isolation option under survivability, and state the invariant
    Filed under survivability rather than performance: whether the mezzanine
    path needs isolation is open, and the cost of being wrong is a respin --
    hundreds of dollars and weeks of overseas transit -- against a cost of
    being right of zero. Same reasoning as the QSPI PSRAM on the flash bus.
    States the invariant explicitly because the failure mode is worse than
    simply not getting isolation. Exactly one of the two is present: bridge
    OR transceiver, never both. Default is bridge intact and the xx245 DNP;
    if you stuff the 245, you cut the bridge.
    A stuffed xx245 with the bridge left intact is a transceiver driving in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
2026-08-15 HARD SPEC: the mezzanine is a 486SX-class bus, not a 32-bit 486 bus
    16-bit data, 24-bit address. The naming is deliberate diligence rather
    than shorthand: it promises the intersection of both CPU variants, so a
    daughterboard designed against it works whichever CPU is fitted. A
    mezzanine written against a 32-bit bus would break the moment an
    SX-class part was populated, and the label is what prevents someone
    assuming otherwise.
    It aligns with decisions already made. The pin-saver option puts both
    variants at a 16 MB address space anyway, and the CL-GD5428 has a 16-bit
    host interface, so the first intended daughterboard wants exactly this.
    Fewer connector pins is a free consequence.
    The draw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
2026-08-15 Correct the mezzanine bus name: 386SX, not 486SX
    486SX means "486 without FPU" -- it is a 32-bit part. So "486SX bus"
    reads as a full 32-bit 486 bus, which is exactly the misreading the
    label was introduced to prevent.
    The 16-bit lineage is the 386SX, and the SLC/SXLC parts that share its
    pinout. The "SX" in TI486SXLC refers to the 386SX pinout, not to the
    Intel 486SX -- which is precisely the collision that makes this worth
    stating rather than assuming.
    Corrected in the diagram and in BOARD.md, with the reasoning recorded so
    it is not "corrected" back by someone reading 486-class CPU support and
    assuming the bus name should match the CPU.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
2026-08-15 Clocking: one 50 MHz oscillator on a GPLL0 input
    Everything else is synthesised on-chip -- CPU bus clock, memory clock,
    pixel clock -- so the board carries one clock source rather than several.
    That is the right trade on a pin-constrained design: a dedicated PLL
    input costs one pin and removes the need for separate oscillators and
    their pins elsewhere.
    It must land on a dedicated GPLL input rather than general I/O. Records
    all four GPLL0 inputs from the pin map, one per die corner: A4/A5 in bank
    7 and P3/P4 in bank 6 on the left, C18/D17 in bank 2 and U16/T17 in bank
    3 on the right, with GPLL1 also available at the two upper corners on PT.
    Cost is one pin for a single-ended source -- drive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
2026-08-15 Note SDRAM runs at CPUCLK x 2
    With a 33 MHz CPU bus that is ~66 MHz, and both fall out of the 50 MHz
    reference on clean ratios: 50 x 2/3 = 33.33 MHz for the CPU bus and
    50 x 4/3 = 66.67 MHz for SDRAM, which is exactly twice.
    The point is not bandwidth -- the memory is already over-specified for
    this machine -- it is the fixed integer phase relationship. At exactly
    2x the memory controller gets two SDRAM cycles per CPU cycle with no
    clock-domain crossing and deterministic timing between the two, which
    removes synchroniser latency from precisely the path the latency
    argument is about.
    Noted on the SDRAM block in the diagram, in the pin budget, and in the
    clocking section beside the oscillato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
2026-08-15 README: reframe the opening as philosophy rather than pitch
    The previous version had drifted into selling. "The best machine we
    could design", "room to tinker, if you are up for it", and a bolded
    "continuable by someone else, not merely forkable" all read as taglines
    -- claims about how good the project is rather than statements of how it
    is built.
    Rewritten in a declarative register. The same four ideas remain --
    latency over bandwidth, deliberate slack, constraints before solutions,
    and the decision record as the thing that outlasts the authors -- but
    stated as working principles rather than advertised as virtues. No bold
    pull-quotes, no invitation, no superlatives.
    Also keeps the observ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
2026-08-15 Record why PMOD rather than a period connector
    New ideas are welcome; they are expected to arrive in a modern idiom.
    That gives the board two expansion paths, each in its own era's terms:
    the mezzanine for period parts, speaking a 386SX bus at 3.3 V, and PMOD
    for anything new, speaking a standard modern header.
    Which is the organising principle applied to expansion rather than to
    peripherals: period where it has to be, modern where it can be. A period
    part needs a period bus and gets one. Anything designed today has no
    reason to pretend, and should not be made to.
    It also resolves an apparent tension in the plan -- "no expansion slots"
    alongside two expansion connectors. There are no perio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
2026-08-15 Say "no legacy expansion slots", and record why that is a conclusion
    The absence is of legacy slots specifically, and it is a conclusion
    rather than a constraint imposed by the form factor.
    Building an expansion ecosystem around period cards is a dead end: the
    supply only shrinks, every card needs the bus reproduced faithfully
    enough to satisfy hardware nobody can fix, and the effort scales with a
    catalogue that is closed. So the board does not chase it.
    What it does instead is targeted. The mezzanine supports the specific
    legacy silicon that earns its place -- today that is one video chip --
    and nothing more, while anything new arrives on a modern header that is
    still manufactured. Both p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
2026-08-15 README: embed the placement drawing on the landing page
    The parts list describes blocks; the drawing shows how they sit against
    the FPGA edges, which is the part that is hard to picture from prose.
    Embedded inline after that list rather than linked, so a visitor sees the
    machine without following anything.
    Caption states what the drawing does and does not claim -- general
    placement, orientation not fixed, pin counts counted from the datasheet
    CSVs rather than estimated -- and points at PLACEMENT.md for the
    derivation.
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2026-08-15 Scope the first mezzanine spec pass to physical, electrical and pinout
    Records the sequencing decision and why it is the right order rather than
    merely a convenient subset.
    Connector, pinout and electrical limits are a one-way door: changing them
    later means a board spin for everyone who has already built a card
    against them. Cycle extension, interrupts and decode ranges are protocol,
    and protocol lives in a bitstream that can be revised without anyone
    reworking hardware. Settling the irreversible layer first stops it
    holding up the revisable one.
    It is also the layer that unblocks other people soonest. With connector,
    pinout, voltage limits and timing budget published, a card can be laid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
2026-08-15 README: say why each sub-project exists, not just what it is
    The list read as four loosely related repositories, which left ao486 in
    particular looking ambiguous -- a second x86 core next to a hard CPU and
    an interpreter invites the question of which one the project actually
    means.
    It is there for survivability. NOS Am5x86 is finite and not being made
    again, so a 486-class core inside the FPGA is what keeps the board
    buildable after the supply of period parts is gone. That is a deliberate
    position and the table should state it rather than leave a reader to
    infer it.
    The other three get the same treatment: the co-simulation exists so the
    machine works before hardware does, tiny386 so a boar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
2026-08-15 Fake TMDS: settle most of the G2 gate from the datasheet, and correct a placement error it exposes
    Worked the ECP5 datasheet (FPGA-DS-02012-1.9) before spending an
    afternoon on hardware, and most of the gate falls out on paper.
    Three facts, in the order they bind. Emulated differential output is
    available on every bank, which confirms the position already recorded.
    But the output gearing is on the left and right sides only -- the top
    side supports 1x gearing -- and gearing is what sets the data rate. The
    buffer is available everywhere; the serialiser is not. That gives 500
    Mb/s on any edge, and 624/700/800 Mb/s on left/right by speed grade.
    Against a 10x pixel clock that puts every mode DO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
2026-08-15 Fake TMDS: correct the coupling -- capacitors, not a resistor network
    The ULX3S GPDI lines are series AC-coupled, 220 nF and 100 nF on a later
    fork. Earlier notes here called it a resistor network, which is wrong.
    It is also the correct approach, for a reason specific to the sink: a
    TMDS receiver terminates each line with 50 ohm to AVCC, and that
    termination sets the DC bias. Driving push-pull LVCMOS33 into it directly
    fights that bias, so series capacitors block the DC and let the swing
    ride on the bias the sink has already established. Industry guidance for
    TMDS coupling is 75-200 nF, which is where the ULX3S sits.
    Records where the error came from, because it is an easy one to repeat.
    L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
2026-08-15 Fake TMDS: read the Tang Nano 9K front end, and correct two claims about it
    Read Sipeed's schematic and source rather than assuming, and both earlier
    claims about the board were wrong in the same direction -- they
    understated it.
    It uses ELVDS_OBUF, Gowin's emulated LVDS, not TLVDS_OBUF. Earlier notes
    here said true LVDS and concluded the board could say nothing about
    emulated differential signalling. The opposite is true: it is the same
    class of technique planned here, complementary CMOS emulating a
    differential standard into a TMDS sink, driven by a hard 10:1 serialiser
    with the pins in a 3.3 V bank.
    And its front end is AC-coupled, which settles the coupling question from
    a second indep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
2026-08-15 Fake TMDS: oversize the 49.9 ohm pull-up footprints on prototypes
    These eight resistors should be 0805 or 1206 rather than 0402 on
    prototype builds, specifically so they are easy to lift with an iron.
    The pull-up is the one element of this front end adopted on the authority
    of another board rather than measured on ours. If it proves wrong here --
    wrong value, or unwanted against a particular sink -- the fix is removing
    or changing eight parts on assembled hardware. Making that a five-minute
    rework costs nothing at prototype stage, and the package can shrink once
    the value is confirmed.
    Same reasoning as the DNP footprints and cuttable bridges in BOARD.md:
    survivability.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
2026-08-15 Fake TMDS: EDID and DDC are out of scope
    The machine emits a small fixed set of VESA modes and the display accepts
    them or does not. A DOS machine has nothing to negotiate -- the guest
    picks its mode, and nothing downstream is going to choose a better one
    from a capability list. That is what VESA timings are for.
    What it removes is more than parts: an I2C master in RTL, a 5 V
    level-shifting domain on an otherwise 3.3 V board, and a runtime
    negotiation path with its own failure modes. The DDC pads and pull-up
    footprints stay DNP, since without them adding EDID later is a board
    spin.
    Two consequences recorded rather than left implicit. A sink does not
    require the source to read it -- DVI and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
2026-08-15 Fake TMDS: keep EDID, drop DDC -- the blob comes from a ROM
    Separates the wire from the data, which are usually one thing and do not
    have to be.
    DDC, the I2C wire to the monitor, is out: it removes an I2C master in
    RTL, a 5 V level-shifting domain on an otherwise 3.3 V board, and a
    runtime negotiation path with its own failure modes. EDID, the data
    structure, stays -- supplied from a small ROM. The mode logic still
    consults a real EDID blob rather than a mode list baked into RTL.
    And the ROM can be supplied upstream by the ESP32, over the mechanism
    already carrying the CMOS time base, etc/e820 and the NE2000 MAC address:
    the chipset reset-exit vector reads configuration from the controller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
2026-08-15 Fake TMDS: 0 ohm DNP pads at the connector so DDC is bodgeable to PMOD
    Supersedes the previous position that adding DDC later would be a board
    The DDC pins get 0 ohm footprints at the connector, DNP, with the far
    side landing on an isolated pad rather than a routed net. Nothing reaches
    the FPGA, so the connector pins, the 5 V domain and the RTL are all still
    saved -- but the signals sit at a pad instead of stopping dead.
    Recovering the capability then means stuffing the 0 ohm parts and running
    wire to spare PMOD I/O, of which there is a deliberate surplus. The I2C
    master becomes bit-banged on general PIO, which is cheap. An afternoon of
    rework rather than a respin. Applies to SCL, SD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
2026-08-15 Distinguish the 5 V rail from the 5 V domain
    The board takes +5 V in and derives +3V3, +2V5 and +1V1 from it, so a 5 V
    rail is available for connectors, USB VBUS, a display's +5 V pin, fans
    and anything else that wants it. What is prohibited is a 5 V signal
    reaching an FPGA pin.
    Worth stating explicitly because "no 5 V on the board" is wrong and would
    rule out things that are fine, while "nothing in the 5 V domain connects
    directly to the FPGA" is the actual constraint and the one to raise in
    review. Same principle already applied at the mezzanine, now stated as a
    board-wide rule rather than a per-interface one.
    Corrects the fake-TMDS text, which described dropping DDC as removing "a
    5 V d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
